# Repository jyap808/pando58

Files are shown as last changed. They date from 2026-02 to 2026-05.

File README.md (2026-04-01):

# Pando58

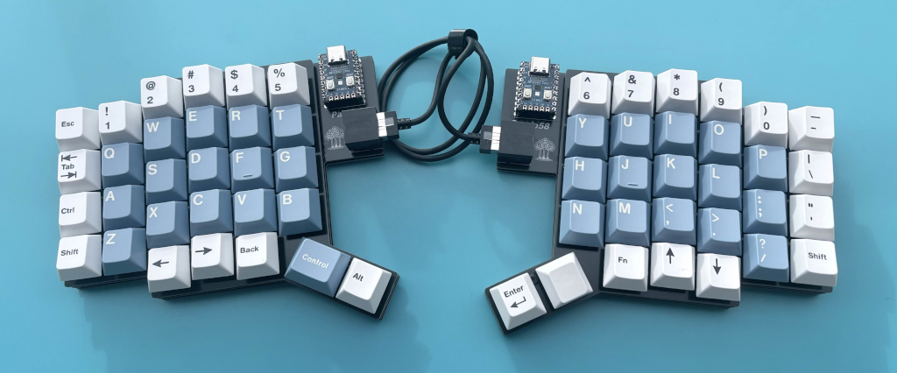
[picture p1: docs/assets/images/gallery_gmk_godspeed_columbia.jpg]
Pando58 with GMK Godspeed Colombia


Pando58 is a modern RP2040 Zero-based 58-key column staggered split keyboard. The PCB supports hotswap sockets OR soldered switches. The interconnect uses RJ45 ports as opposed to TRRS, which improves reliability and allows for hotplugging.

> [!NOTE]
> 📘 The **[Documentation pages](https://jyap808.github.io/pando58)** contain a Bill of Materials, Build guide, Firmware guide and Gallery.

> [!TIP]
> 🚀 Want to build one? Official PCB sets and full DIY kits are available on [Etsy](https://www.etsy.com/listing/4478359437/). Your support helps me keep this project open-source and encourages the development of new models!

## ⌨️ Overview

- **Layout:** Split ergonomic, 58 keys total  
- **Split connection:** RJ45 (no TRRS)  
- **MCU:** 2× RP2040 Zero  
- **Firmware:** Vial  

## 💡 Design Philosophy

Pando58 was designed to avoid unnecessary complexity and common failure points found in many split keyboards.

### Why RJ45 instead of TRRS?

TRRS cables are widely used in split keyboards, but they have a major drawback:

- ❌ **Not hot-plug safe** — plugging or unplugging can short pins and damage MCUs

Pando58 uses **RJ45** to solve this:

- ✅ Hot-plug safe
- ✅ Mechanically robust
- ✅ Readily available cables and plugs
- ✅ Clear pin separation and predictable wiring

For more details on the design and development process, see my [blog post](https://julianyap.com/posts/2026-03-26/).

## 🟢 Electronics

- **MCUs:** 2× RP2040 Zero  
- **PCBs:** Dedicated left and right designs (not reversible)

### Why dedicated PCBs?

Reversible PCBs often introduce increased chance of assembly errors.

Pando58 intentionally uses **separate left and right PCBs** to:
- Simplify assembly
- Reduce mistakes
- Improve electrical clarity

## ⚡ Switch & Diode Support

Pando58 is designed to accommodate different builder preferences and budgets:

- **MX switches**
- **Hot-swap sockets** (optional)
- **Solder-only sockets** (no hot-swap sockets required)
- **Diodes**
  - Supports **SMT diodes**
  - Supports **through-hole diodes**

Choose the configuration that best fits your workflow and tooling.

## 💾 Firmware

- **Vial firmware provided** (see `keyboards/` directory)
- Instant key remapping
- No recompiling required
- Works out of the box once flashed
- Compiled firmware available in [Releases](https://github.com/jyap808/pando58/releases)

## 📦 Case Options

Pando58 is intentionally flexible in enclosure options:

### FR4 Sandwich Case

- Minimal
- Affordable
- Easy to manufacture
- Gerber files are available in [Releases](https://github.com/jyap808/pando58/releases)

### 3D-Printable Case

- Allows experimentation with angle and height
- Source FreeCAD file in `case/` directory
- Ready-to-print STL available on [Printables](https://www.printables.com/model/1647072-pando58-case)

## 🛠️ Tooling & Design

- Generated using **Ergogen**
- Custom footprints created for:
  - RJ45 connector
  - RP2040 Zero (heavily modified from existing designs)

## 📷 Photos

Additional photos are available in the [Gallery](https://jyap808.github.io/pando58/gallery).

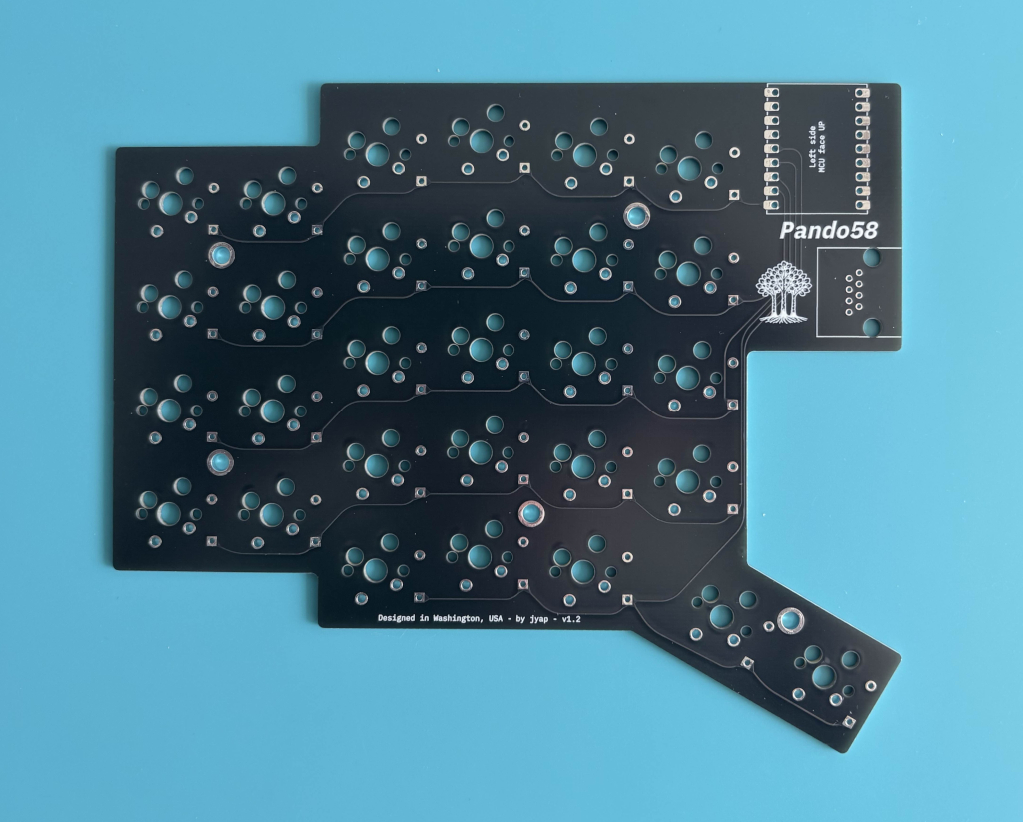
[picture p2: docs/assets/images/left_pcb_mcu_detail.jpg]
Left PCB top side

Left PCB top side

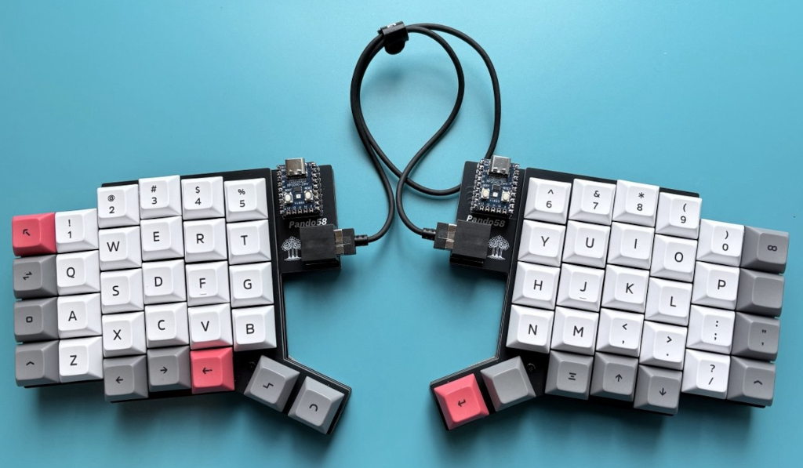
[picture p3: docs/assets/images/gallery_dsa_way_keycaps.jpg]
DSA Way Keycaps

Standard layout build with DSA Way keycaps

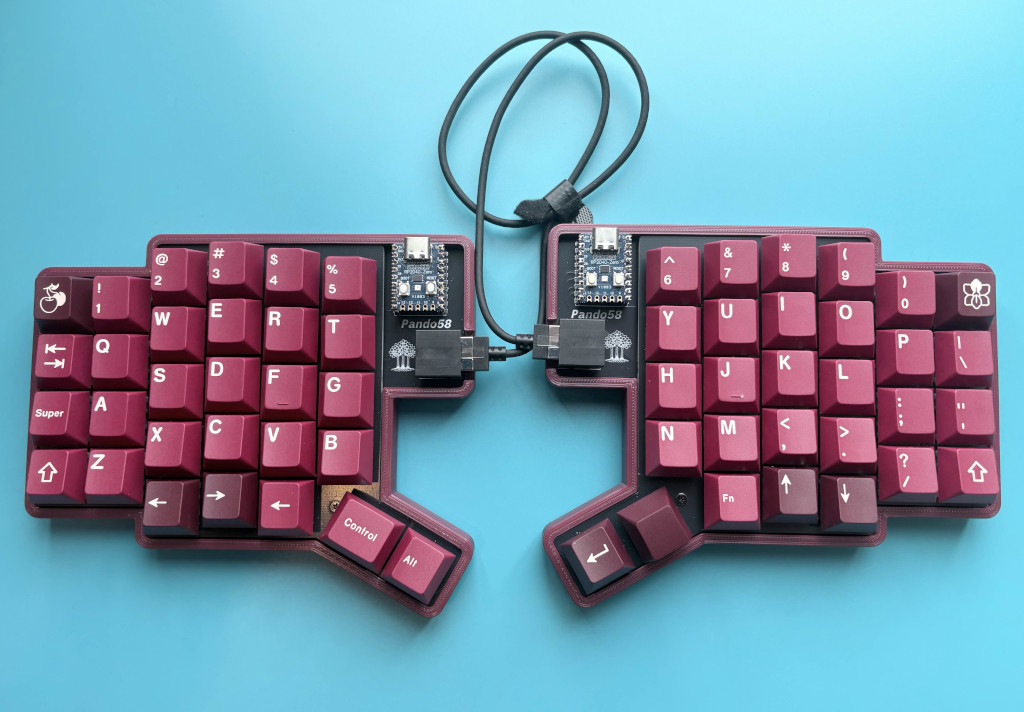
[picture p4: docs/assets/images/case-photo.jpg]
Pando58 3D printed case

3D printed case with Keykobo Cherries

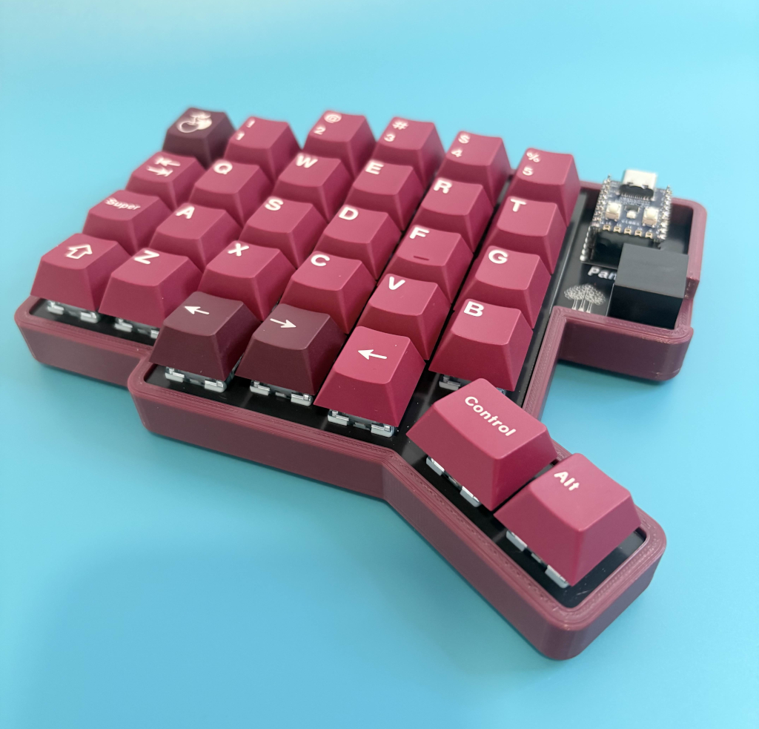
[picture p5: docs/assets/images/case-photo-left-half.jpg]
Pando58 3D printed case - left half

3D printed case - left half

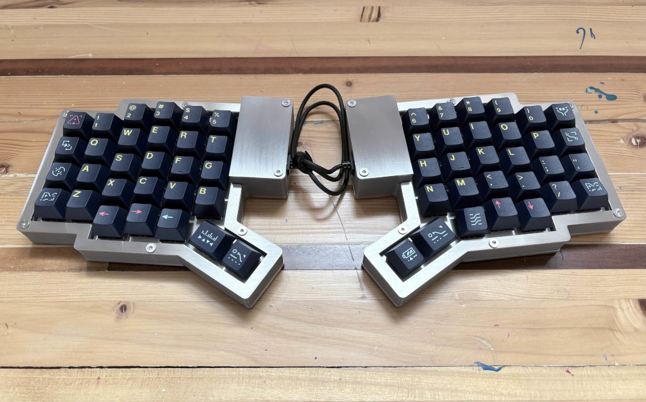
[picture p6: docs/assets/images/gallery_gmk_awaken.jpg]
GMK Awaken

Custom stainless steel and 3D printed case - GMK Awaken keycaps.

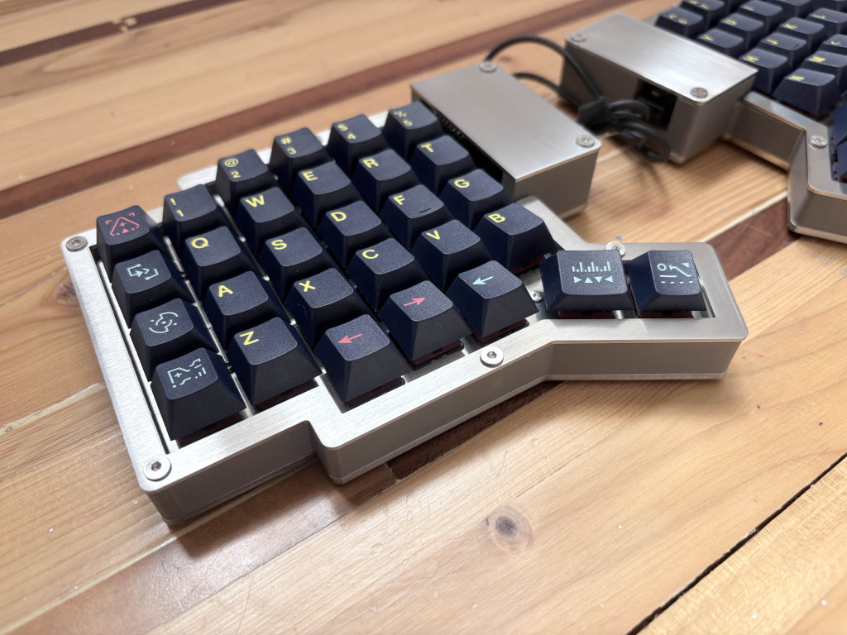
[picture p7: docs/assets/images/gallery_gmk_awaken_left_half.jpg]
GMK Awaken Left Half

The same build from a different angle showing the left half.

## 📄 License



[Pando58 Keyboard](https://github.com/jyap808/pando58) © 2026 by [Julian Yap](https://julianyap.com/) is licensed under [CC BY-SA 4.0](http://creativecommons.org/licenses/by-sa/4.0/?ref=chooser-v1)

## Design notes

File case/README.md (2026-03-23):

# Pando58 Case

Pando58 Case

3D printable case for Pando58 keyboard.

This replaces the default FR4 bottom piece. The assembled keyboard uses: switch plate + PCB + bottom case (this piece).

**Note:** This model represents the **LEFT side** only. To print the right side, mirror the model in your slicer.

## Printing

The ready-to-print STL file is available on [Printables](https://www.printables.com/model/1647072-pando58-case).

Pando58 Case - Left Half

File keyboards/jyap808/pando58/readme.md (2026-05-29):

# Pando58

Pando58 - 3D printed case

Pando58 - Layered build

*58-key columnar split keyboard driven by RP2040 Zero controllers, utilizing RJ45 sockets for interconnect.*

[Build guide](https://jyap808.github.io/pando58)

* Keyboard Maintainer: [jyap808](https://github.com/jyap808)
* Hardware Availability: [github/jyap808/pando58](https://github.com/jyap808/pando58)
* Hardware Supported: RP2040 Zero

Make example for this keyboard (after setting up your build environment):

    make jyap808/pando58:default

Flashing example for this keyboard:

    make jyap808/pando58:default:flash

See the [build environment setup](getting_started_build_tools) and the [make instructions](getting_started_make_guide) for more information. Brand new to QMK? Start with our [Complete Newbs Guide](newbs).

## Bootloader

Enter the bootloader in 3 ways:

* **Bootmagic reset**: Hold down the key at (0,0) in the matrix (usually the top left key or Escape) and plug in the keyboard
* **Physical reset button**: Briefly press the button on the back of the PCB - some may have pads you must short instead
* **Keycode in layout**: Press the key mapped to `QK_BOOT` if it is available

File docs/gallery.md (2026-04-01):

# Gallery

Pando58 supports a variety of case and keycap options. Here are some examples to inspire your build.

## Case Options

### Standard Layered Build

DSA Way Keycaps

DSA Way keycaps in red accents by FK Keycaps. DSA is a uniform keycap height.

GMK Godspeed Columbia

GMK Godspeed Colombia keycaps with Cherry Icebergo PBT modifier kit keycaps (from keeb.io).

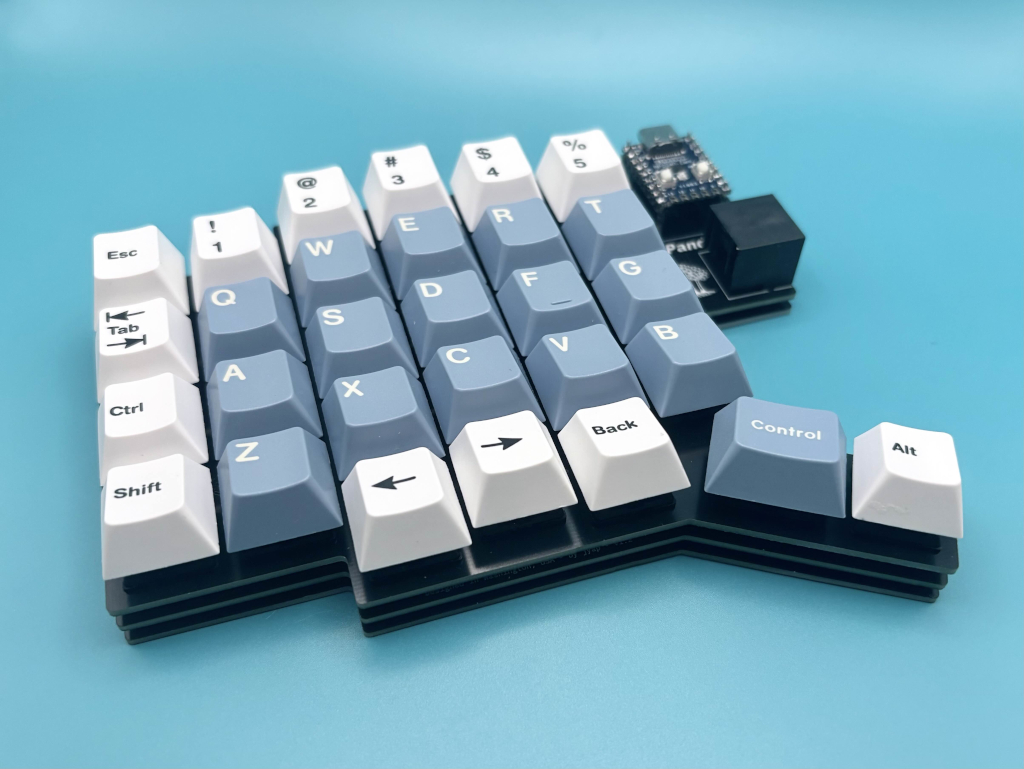
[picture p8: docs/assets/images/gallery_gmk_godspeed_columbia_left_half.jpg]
GMK Godspeed Columbia Left Half


The same build from a different angle showing the left half.

### 3D Printed Case

[3D printable case](https://www.printables.com/model/1647072-pando58-case) for Pando58 keyboard.

This replaces the default FR4 bottom piece. The assembled keyboard uses: switch plate + PCB + bottom case (this piece).

Pando58 3D printed case

Keykobo Cherries with 40s set keycaps, printed with Ambrosia ASA filament in cardovan.

Pando58 3D printed case - left half

The same build from a different angle showing the left half.

### Custom Case Build

This is my custom case build made from stainless steel sheet metal mixed with 3D printed case.

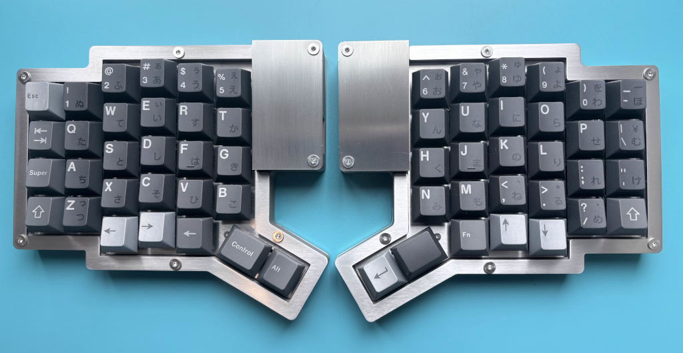
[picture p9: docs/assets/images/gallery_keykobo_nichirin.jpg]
Keykobo Nichirin


Keykobo Nichirin with 40s set keycaps.

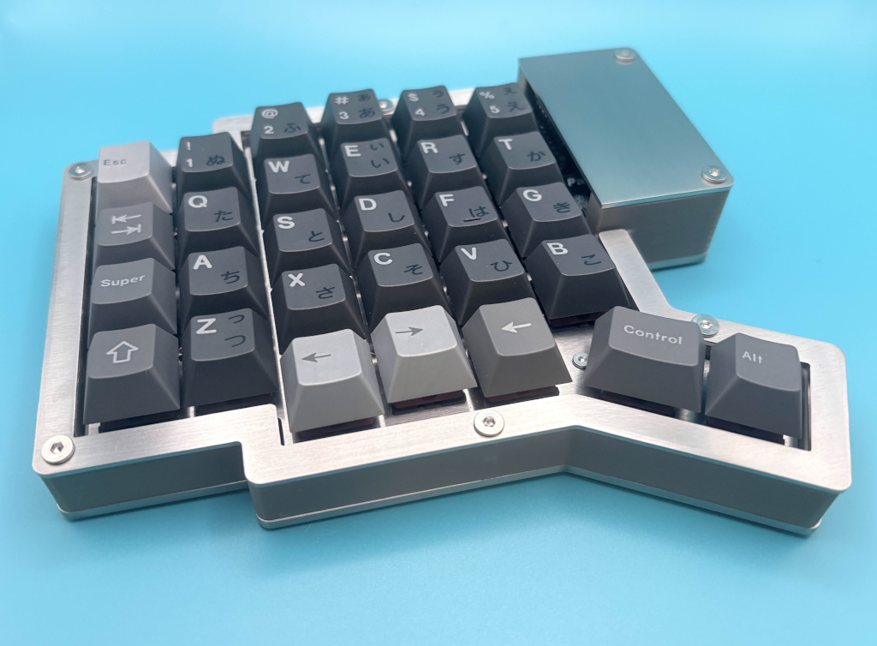
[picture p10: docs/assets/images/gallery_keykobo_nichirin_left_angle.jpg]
Keykobo Nichirin Left Angle


The same build from a different angle showing the left half.

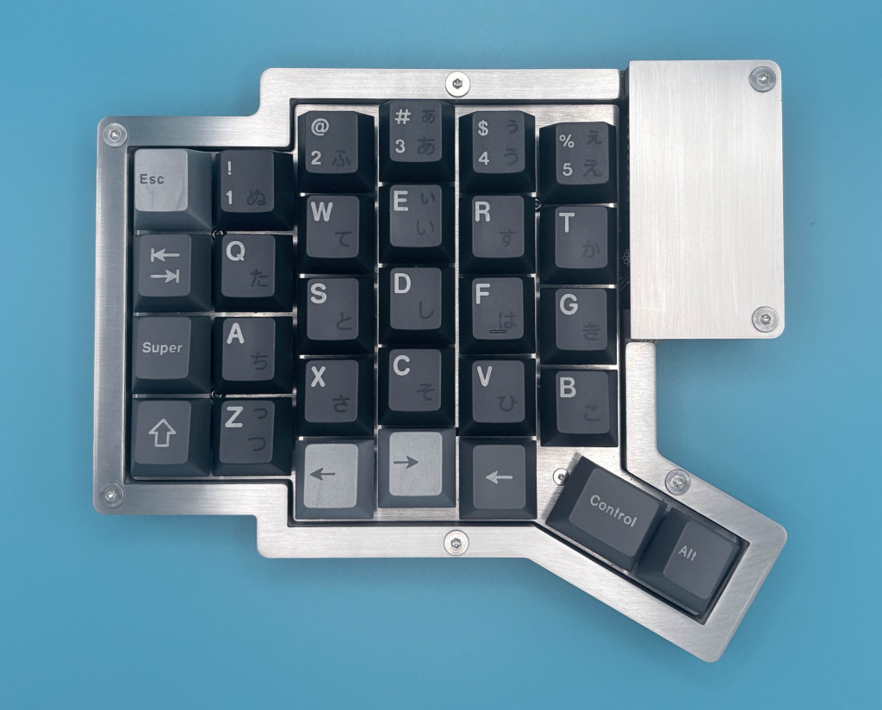
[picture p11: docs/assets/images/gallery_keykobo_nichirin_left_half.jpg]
Keykobo Nichirin Left Half


The same build from a top view showing the left half.

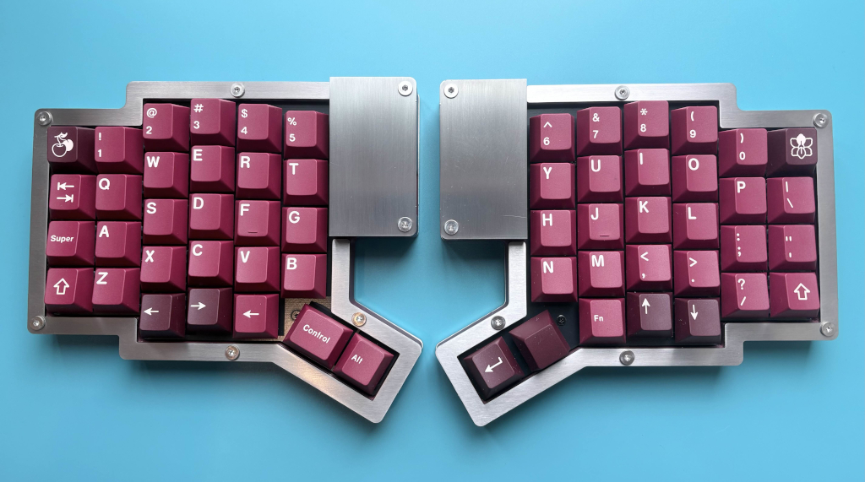
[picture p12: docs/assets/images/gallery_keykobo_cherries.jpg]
Keykobo Cherries


Keykobo Cherries with 40s set keycaps.

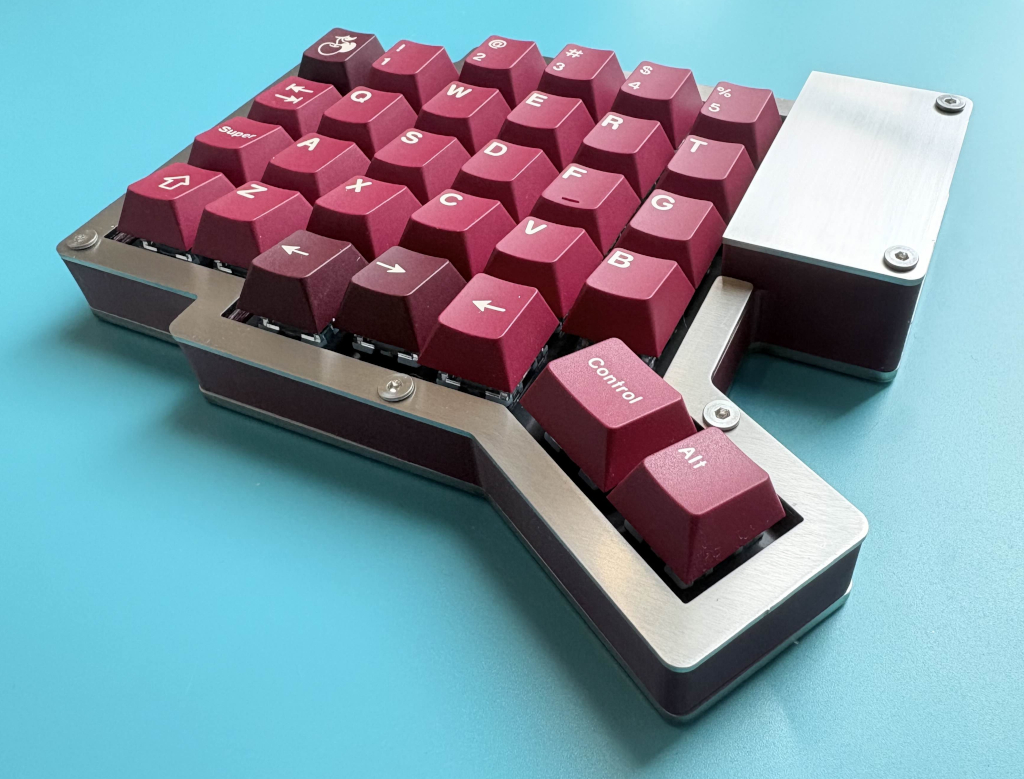
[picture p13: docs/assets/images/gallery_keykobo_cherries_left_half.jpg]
Keykobo Cherries Left Half


The same build from a different angle showing the left half.

GMK Awaken

GMK Awaken keycaps.

GMK Awaken Left Half

The same build from a different angle showing the left half.

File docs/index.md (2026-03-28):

# Pando58 Keyboard

Pando58

Pando58 is a modern RP2040 Zero-based 58-key column staggered split keyboard. The PCB supports hotswap sockets OR soldered switches. The interconnect uses RJ45 ports as opposed to TRRS, which improves reliability and allows for hotplugging.

🚀 Want to build one? Official PCB sets and full DIY kits are available on [Etsy](https://www.etsy.com/listing/4478359437/). Your support helps me keep this project open-source and encourages the development of new models!

## Design Philosophy

Pando58 was designed to avoid unnecessary complexity and common failure points found in many split keyboards. It features:

- Wired connection only (no wireless)
- No LEDs, encoders, or OLED displays
- Simple, reliable construction
- Focus on core typing experience

For more details on the design and development process, see my [blog post](https://julianyap.com/posts/2026-03-26/).

## Inspiration

Pando58 came about through wanting a flat PCB version of my [hand-wired Cosmos Dactyl](https://julianyap.com/posts/2025-11-16-1763340628/). The key layout was inspired by the [Kinesis Advantage2](https://kinesis-ergo.com/keyboards/advantage2-keyboard/#layout) with a simplified thumb cluster.

While not being directly inspired by other keyboards, it can be seen as similar to other keyboards like the Silakka54, Lily58, Sofle and ErgoDox.

### Name

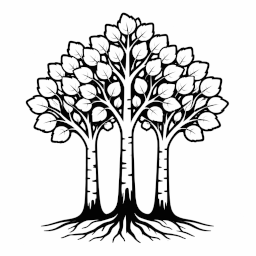
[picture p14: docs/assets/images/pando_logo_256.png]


Pando58 is named after the [Pando tree](https://youtu.be/SwBgSbPvg7Q). I had found out from a [really cool presentation](https://neal.fun/size-of-life/) that Pando was the Earth's largest organism by mass.

This idea maps nicely onto split keyboards. At first glance, a split keyboard looks like two separate devices. But electrically and functionally, they operate as one system: two halves connected together to behave as a single keyboard.

The name Pando58 reflects that concept. Like the Pando colony, the keyboard is composed of multiple visible parts that are actually one coherent organism working together. The two halves mirror each other, share firmware architecture, and communicate continuously.

## Getting Started

Visit the [Build](build.md) page to learn about the build process.

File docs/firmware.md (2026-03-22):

# Firmware

Pando58 uses Vial firmware which needs to be installed on the RP2040 Zero MCUs. Once installed, [Vial](https://get.vial.today/) (the application) is used to configure the keyboard.

## Getting Vial

Download Vial (the desktop application) from the [official website](https://get.vial.today/) for your platform.

Alternatively, you can use [Vial Web](https://vial.rocks) in your browser — no download required.

## Installing Firmware

There are two ways to get the latest Vial firmware for Pando58:

> **Note:** Pando58 is a split keyboard with an MCU on each half. Both MCUs will need to be flashed with the Vial firmware.

1. **Easy method** — Download precompiled firmware from [GitHub Releases](https://github.com/jyap808/pando58/releases) and flash via drag-and-drop (recommended for most users).
2. **Manual build method** — Clone the vial-qmk repo, build locally, and flash via CLI.

### Easy Method: Download from Releases + Drag-and-Drop

1. Go to the [Releases page](https://github.com/jyap808/pando58/releases)

2. Download the latest `.uf2` file (e.g., `jyap808_pando58_vial.uf2`)

3. Put the keyboard into bootloader mode by holding the BOOT button on the MCU while plugging in the USBC cable. The keyboard should mount as a removable drive (e.g., "RPI-RP2", "PICO", or similar).

4. Drag the downloaded `.uf2` file onto the mounted drive

5. The drive will auto-eject and the keyboard will reboot with the new firmware

### Manual Build Method: CLI Build + Flash (Advanced)

1. Clone the official Vial QMK fork:

        git clone https://github.com/vial-kb/vial-qmk.git
        cd vial-qmk

2. Initialize submodules (important for QMK dependencies):

        make git-submodule

3. Clone or download the Pando58 keyboard folder from the [GitHub repo](https://github.com/jyap808/pando58).

    Copy the entire `keyboards/jyap808/pando58/` folder into `vial-qmk/keyboards/jyap808/pando58/`.

4. Compile the Vial firmware:

        make jyap808/pando58:vial

    This produces `jyap808_pando58_vial.uf2`.

5. Flash using the CLI:

        qmk flash jyap808_pando58_vial.uf2

    Make sure you're in the directory with the `.uf2` file, or use the full path.

## Configuring with Vial

Open [Vial](https://get.vial.today/) to configure the keyboard. The Pando58 should connect automatically when the firmware is installed.

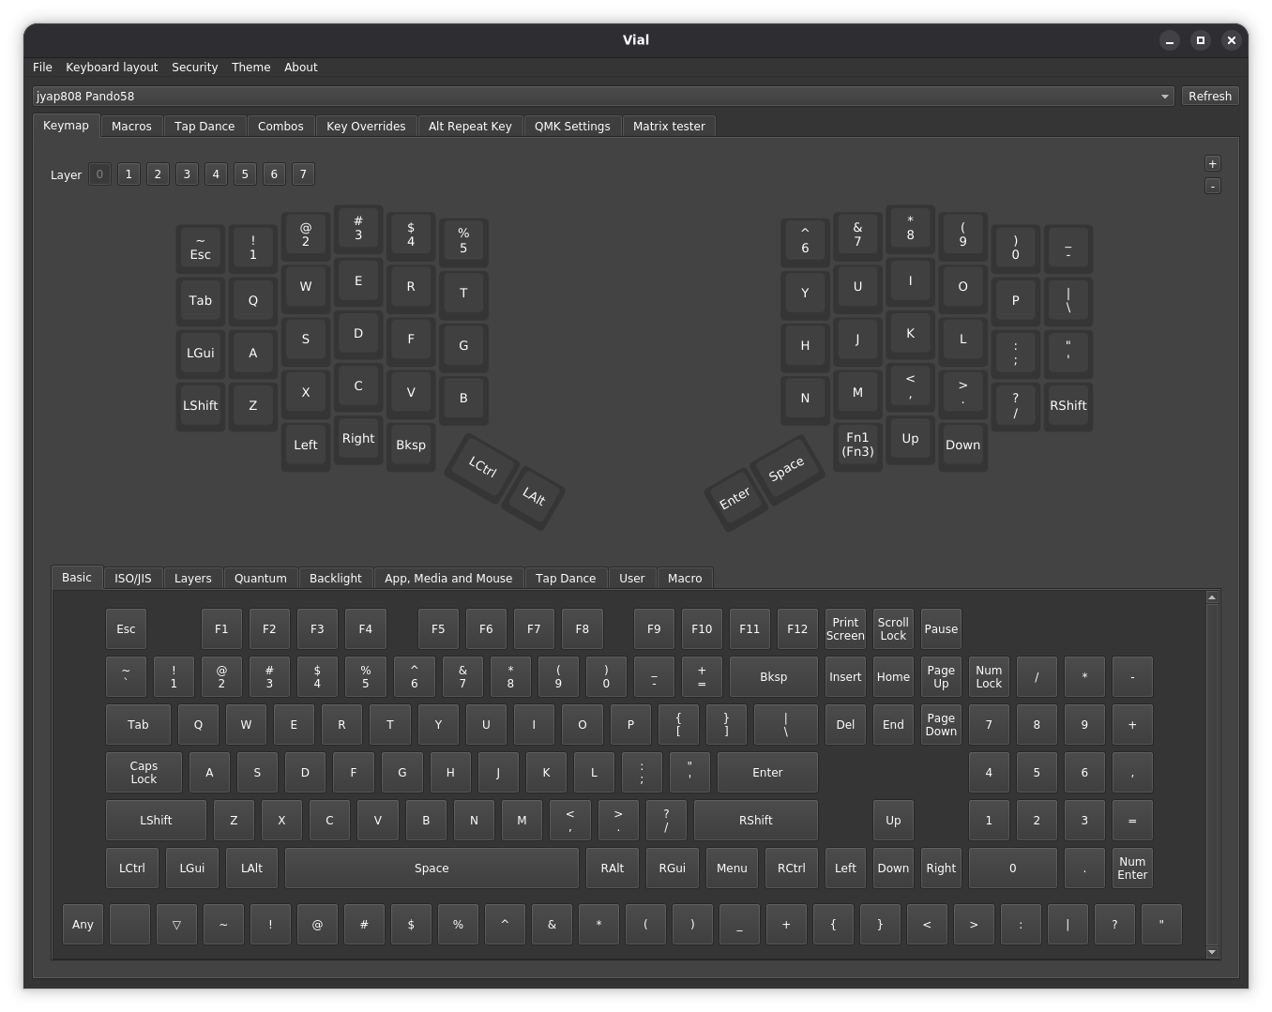
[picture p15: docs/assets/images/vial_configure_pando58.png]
Vial application showing Pando58 keyboard configuration


Vial allows you to remap keys, create layers, and configure macros for your Pando58 keyboard.

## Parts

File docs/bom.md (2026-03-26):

# Bill of Materials

This BOM is for the basic FR4 PCB setup with 2x PCBs (one for each half), 2x switch plates, and 2x bottom plates. Other setups like 3D printed cases are possible but not covered here.

## Components

### Required

#### Electronics

- 2x RP2040 Zero (Waveshare or [clones](https://www.amazon.com/dp/B0DXL1KDY7?tag=fdb-20), one for each half)
- 58x Diodes (1N4148W SMT or [1N4148 through-hole](https://www.amazon.com/dp/B079KJ91JZ?tag=fdb-20))
- 2x RJ45 ports ([Molex 438600001](https://www.digikey.com/en/products/detail/molex/0438600001/410212) or clones with same footprint)
- 2x Pando58 PCBs (left and right, not reversible)
- 4x 9-pin male header pins ([for RP2040 Zero MCU](https://www.amazon.com/dp/B07BRYLMK8?tag=fdb-20), 2 rows per half)

#### Switches & Keycaps

- 58x MX switches
- 58x keycaps

#### Hardware

- 10x M2 8mm brass standoffs ([5 per half](https://www.amazon.com/dp/B0FLGTHV32?tag=fdb-20))
- 20x M2 4mm screws ([10 per half](https://www.amazon.com/dp/B082XXVGT3?tag=fdb-20))
- 2x Pando58 switch plates
- 2x Pando58 bottom plates

#### Cables

- 1x USB-C cable (to connect to computer)
- 1x RJ45 cable ([for interconnect](https://www.amazon.com/dp/B0CMYYN58G?tag=fdb-20))

### Optional

#### Electronics

- 4x 9-pin female header sockets ([for removable MCU installation](https://www.amazon.com/dp/B07BRYLMK8?tag=fdb-20), 2 rows per half)

#### Switches & Keycaps

- 58x [MX hotswap sockets](https://www.amazon.com/dp/B0B4W9YMGM?tag=fdb-20)

#### Hardware

- 8x 3M SJ5302 bumpons ([4 per half](https://www.digikey.com/en/products/detail/3m/SJ5302/2345107))

### Assembly Tools

- Soldering iron and solder
- Screwdrivers
- Kapton tape (optional)
- Flush cutters (optional)
- Tweezers (optional)
- Multimeter (optional)

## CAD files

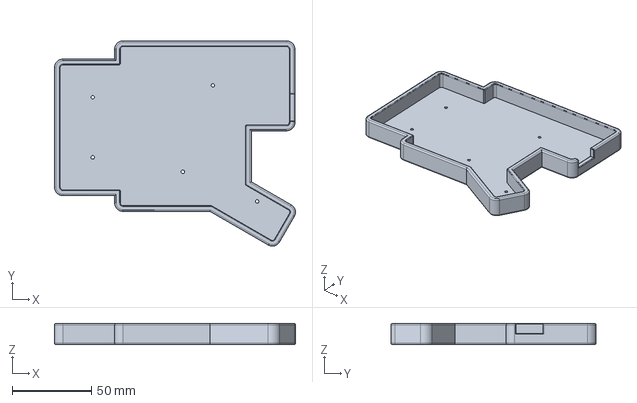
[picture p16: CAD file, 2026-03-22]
case/Pando58Case.FCStd
152.3 x 129.7 x 13.5 mm

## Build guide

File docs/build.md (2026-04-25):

# Build Guide

## Overview

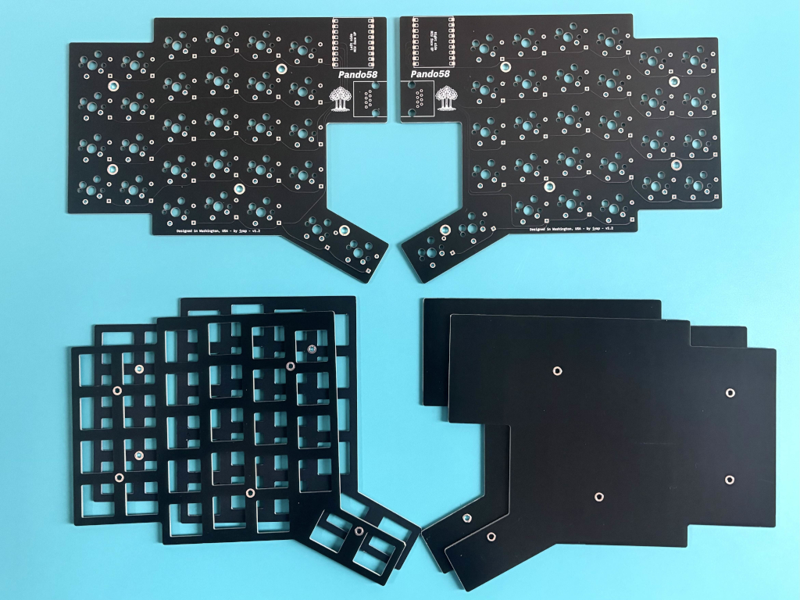
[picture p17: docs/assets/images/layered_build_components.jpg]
All PCB Components for Layered Build


This guide covers the **layered build type** using the dedicated PCBs, 2 reversible switch plates, and 2 reversible bottom plates.

> **Note:** [3D printed case builds](gallery.md#3d-printed-case) are similar (the one-piece case replaces the bottom plates) but are not covered here. Sandwich builds are also not covered.

> **Reference:** See the [Bill of Materials](bom.md) for a complete list of components and quantities needed.

Left PCB MCU Detail

This guide walks through building **one half** (the left half) of the PCBs since the assembly is identical on both halves. Pictured above is the Left PCB top side.

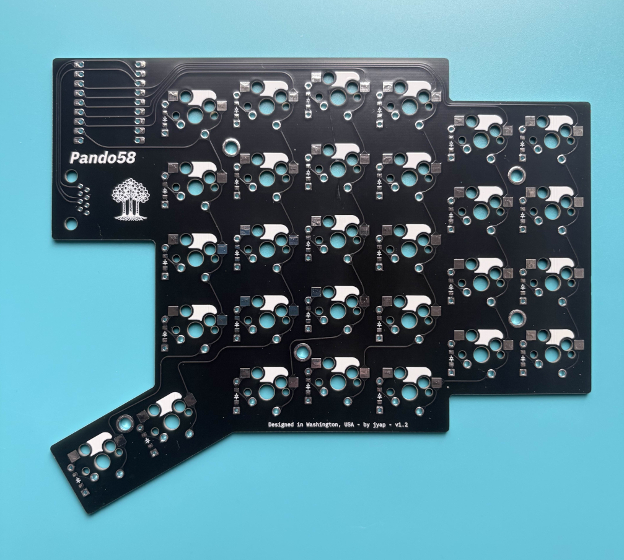
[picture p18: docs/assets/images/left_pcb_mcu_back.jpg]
Left PCB back side


Left PCB back side, ready to be assembled.

## Assembly Steps

This guide covers the following components in detail. Follow each section in order for best results:

1. [Diodes](#diodes) - Through-hole diode installation
2. [Hotswap Sockets](#hotswap-sockets) - MX-compatible switch sockets
3. [RJ45 Port - Interconnect](#rj45-port-interconnect) - Interconnect ports
4. [RP2040 Zero MCU](#rp2040-zero-mcu) - Microcontroller installation
5. [Switches](#switches) - Switch and plate installation
6. [Keycaps and Optional Bumpons](#keycaps-and-optional-bumpons) - Final assembly

### Diodes

Pando58 supports **SMT (surface mount)**, **THT (through-hole)**, or a **combination of both** diodes. This guide covers through-hole diode installation.

> **Note:** If you're using SMT diodes, you should already be comfortable with surface mount soldering or follow a dedicated SMT guide.

**Required:** 58x 1N4148 diodes (29 per half)

#### Bending Diodes

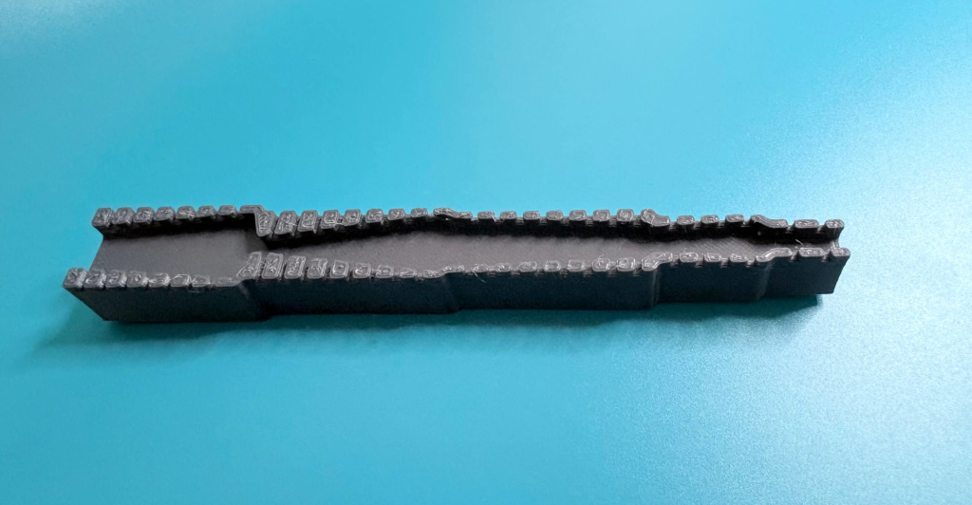
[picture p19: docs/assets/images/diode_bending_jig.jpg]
Diode Bending Jig


Use a bending jig for consistent, clean bends. You can download the 3D model from [Printables](https://www.printables.com/model/739930-bending-jig).

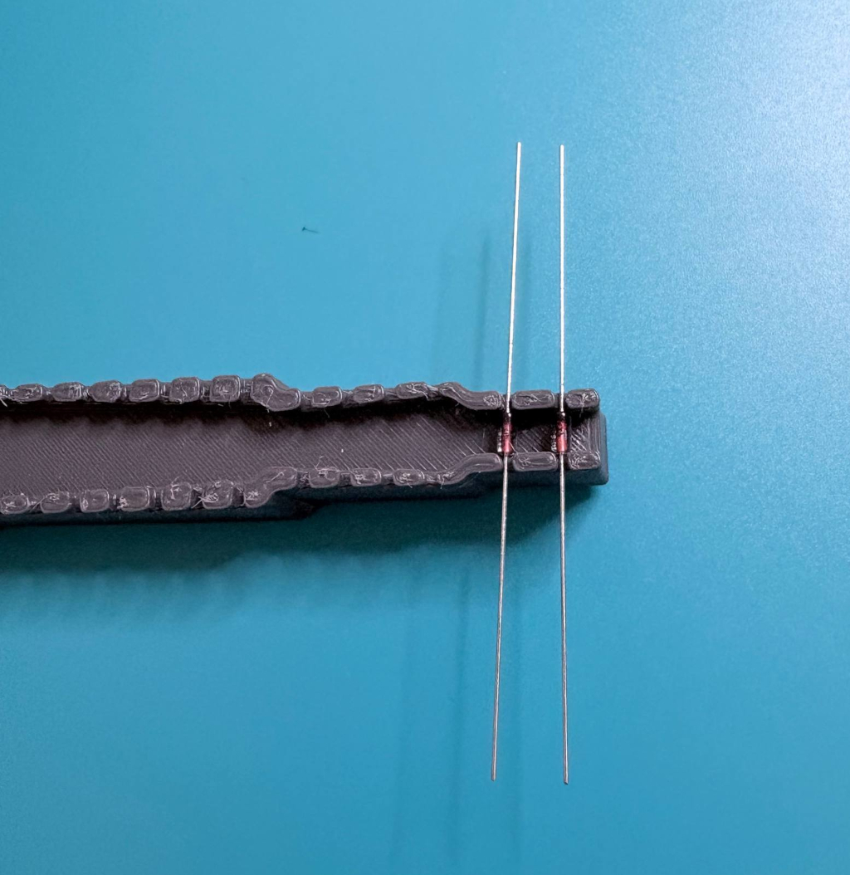
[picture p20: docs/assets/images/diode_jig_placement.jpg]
Diode Placement in Jig


Place the diodes in the jig as shown above.

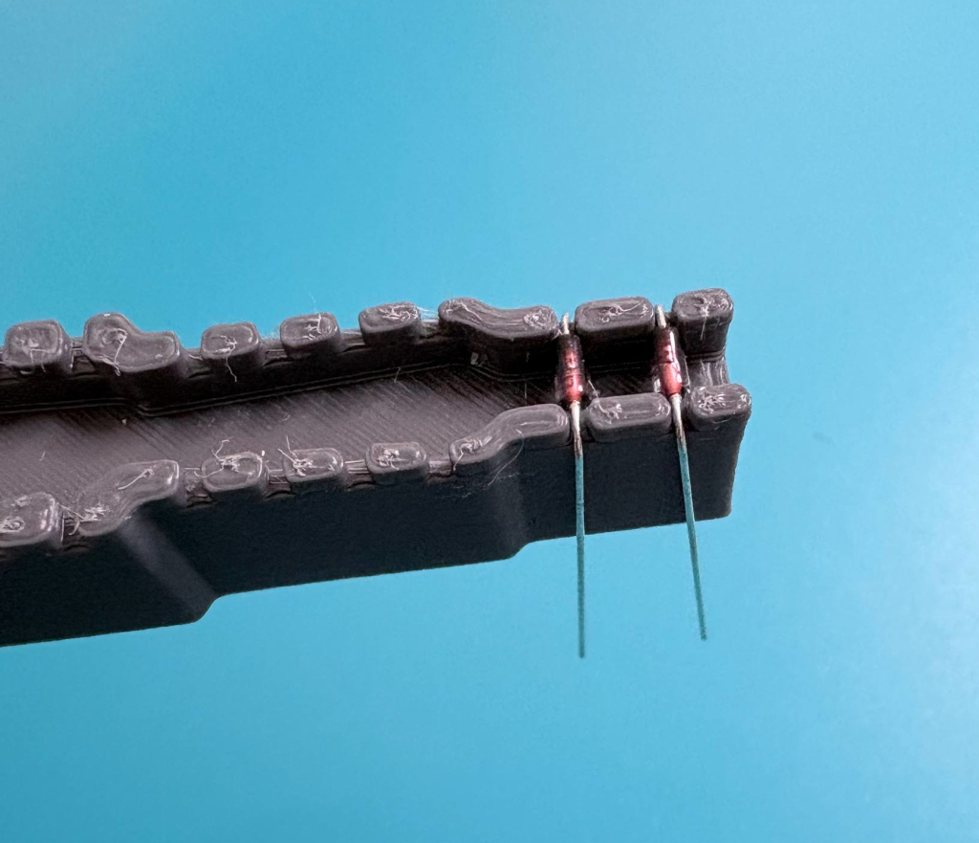
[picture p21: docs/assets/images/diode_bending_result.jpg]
Bent Diodes


The jig bends diodes to a **7.5mm standoff distance**. You can hand-bend diodes at 7.5mm, but the jig produces cleaner, more consistent results.

#### Diode Orientation

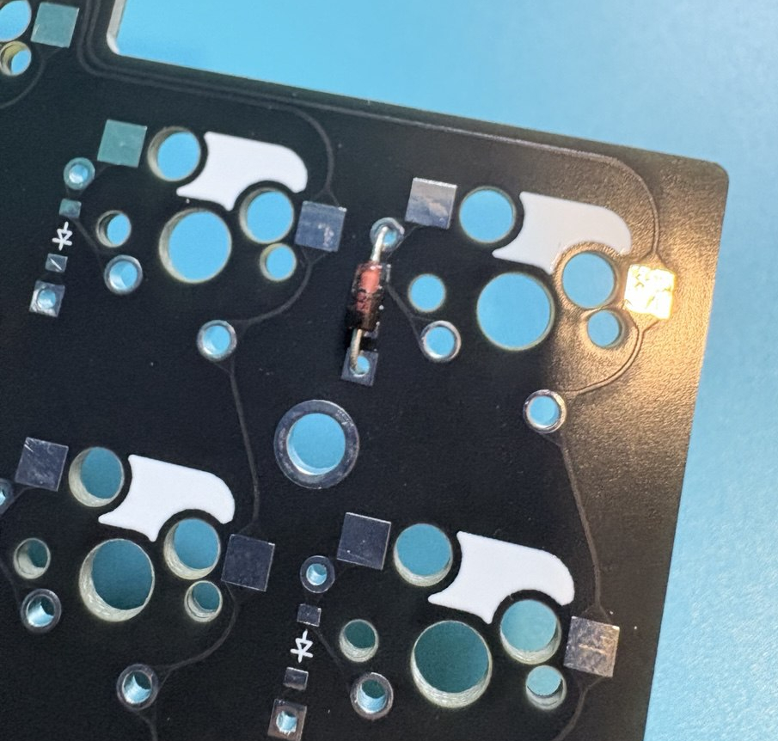
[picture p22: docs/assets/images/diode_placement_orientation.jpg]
Diode Placement Orientation


**Critical:** Diodes are polarity-sensitive components. The **black stripe** on the diode indicates the **cathode (-)** side and must align with the direction arrow shown on the PCB silkscreen.

- The diodes feed through the **BOTTOM** of the PCB
- The black stripe must face the direction of the arrow in the PCB diagram
- Getting this wrong will cause the keyboard to malfunction

#### Populating the Board

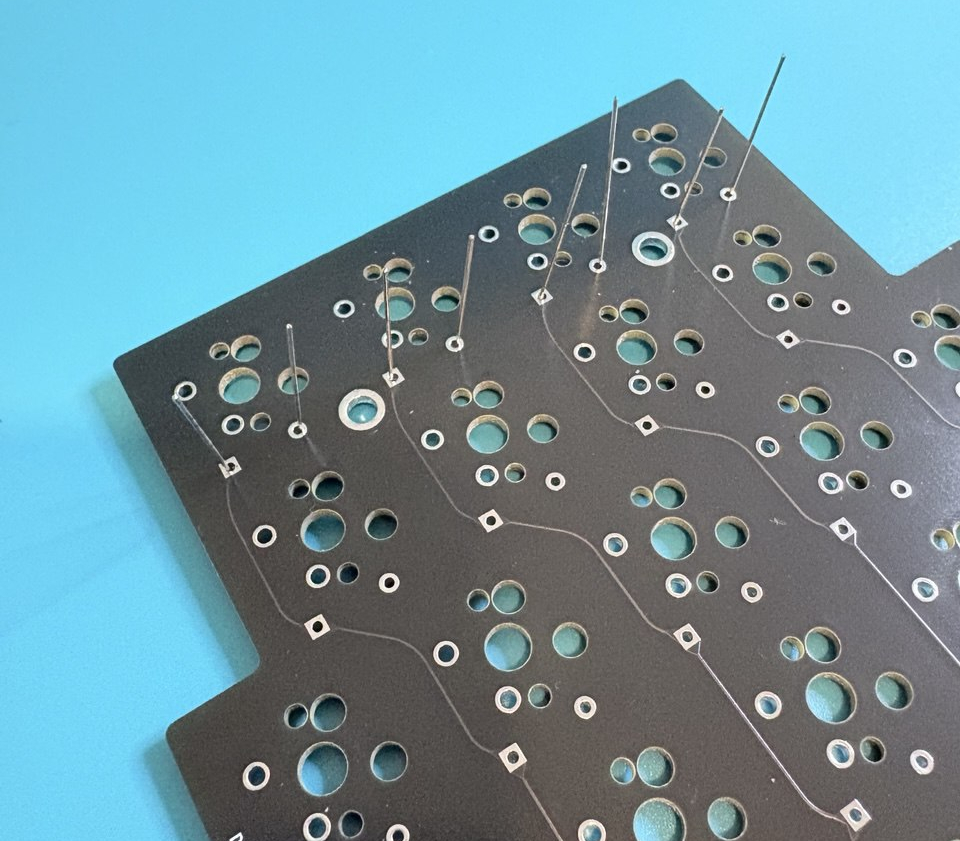
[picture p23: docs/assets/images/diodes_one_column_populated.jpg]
Diodes One Column Populated


Insert the diodes into one PCB half. The board above shows one column populated as an example.

> **Tip:** Solder one column at a time to keep the workspace organized and reduce the chance of diodes falling out before soldering.

#### Soldering Diodes

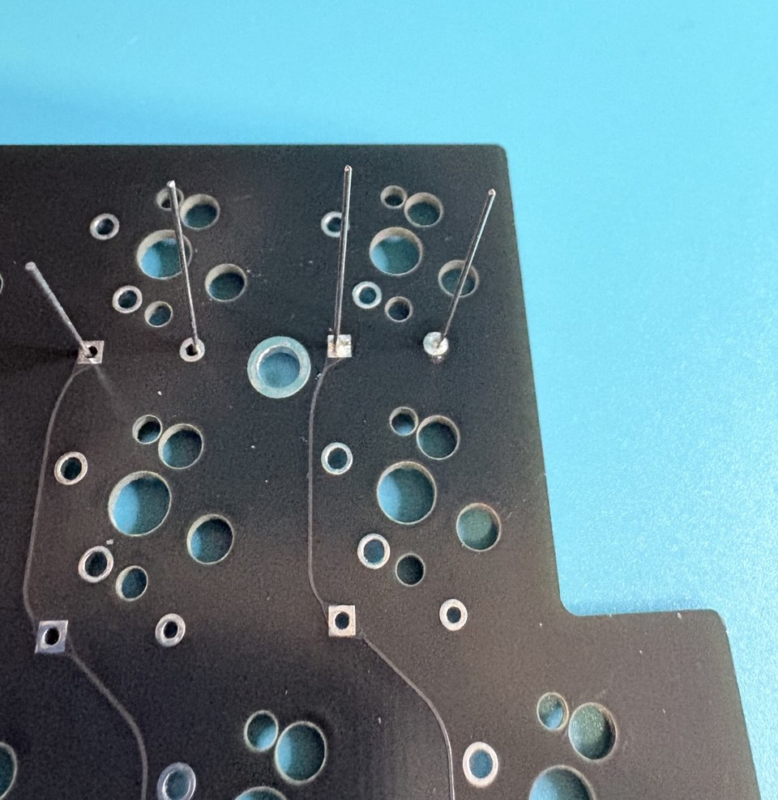
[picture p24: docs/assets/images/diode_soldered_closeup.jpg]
Diode Soldered Close-up


Solder the diodes through the **TOP side** of the PCB. Ensure the diodes lie **flat against the board** while soldering to prevent uneven joints.

**Key points:**

- Apply heat to the pad and leg simultaneously
- Feed solder to create a smooth, concave joint
- Avoid overheating (keep soldering time under 3 seconds per joint)
- Make sure diodes remain flat against the board

#### Trimming Excess Leads

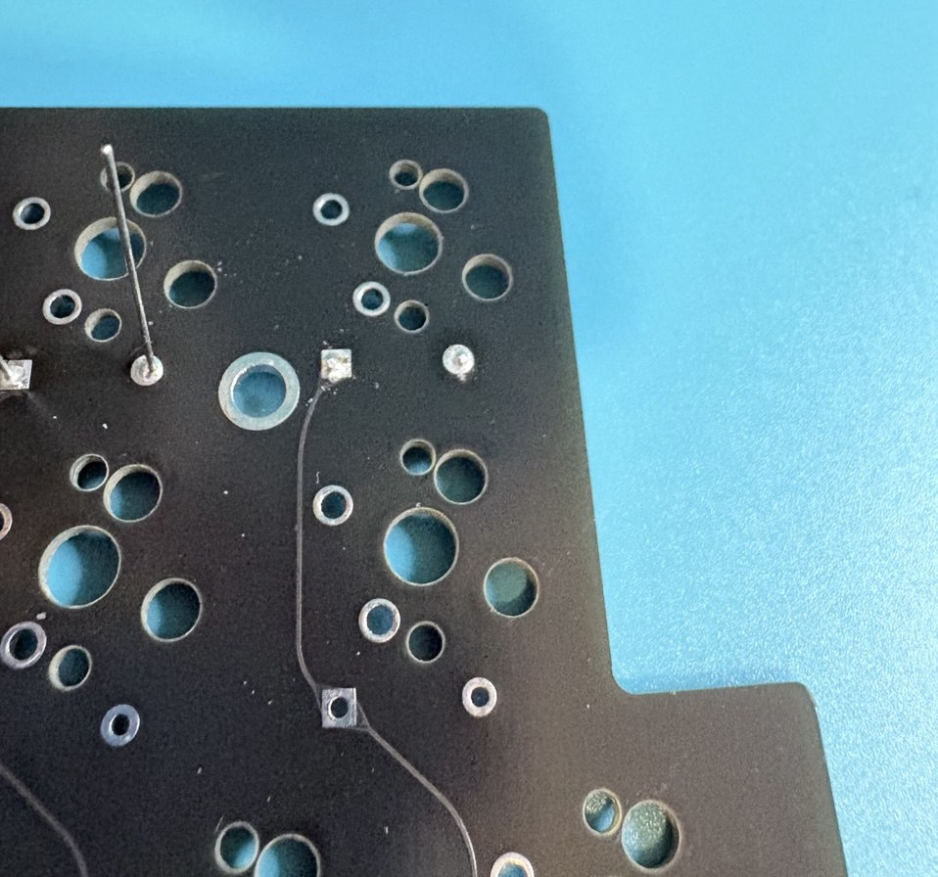
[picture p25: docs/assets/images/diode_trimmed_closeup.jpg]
Diode Trimmed Close-up


Use **flush cutters** to trim the diode legs close to the solder joint after soldering. This prevents sharp edges and reduces the risk of short circuits.

#### Completed Diode Installation

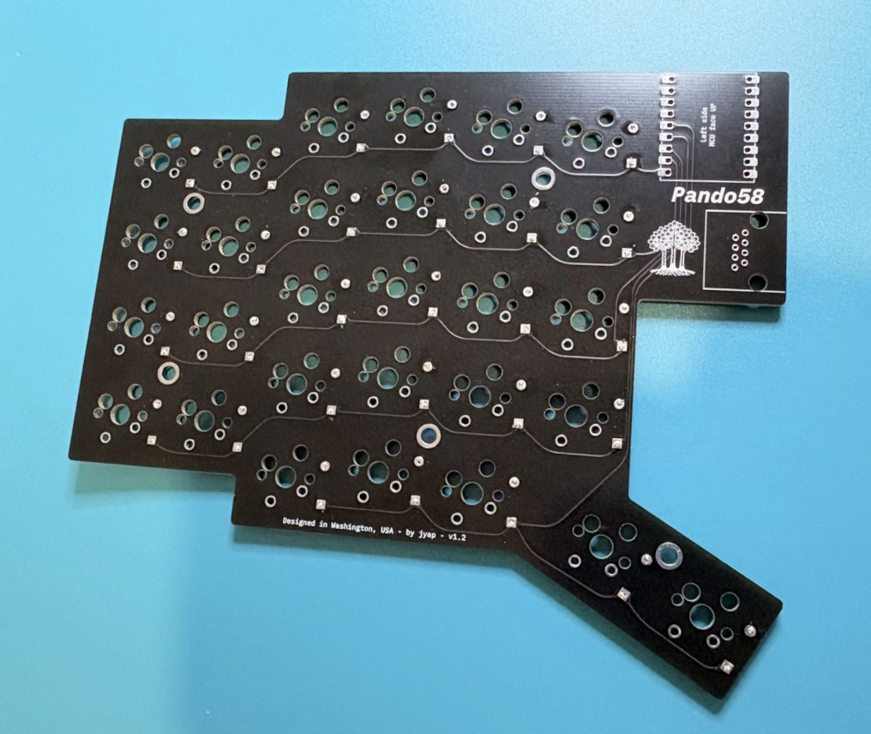
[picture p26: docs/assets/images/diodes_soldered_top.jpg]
Diodes Soldered Top Side


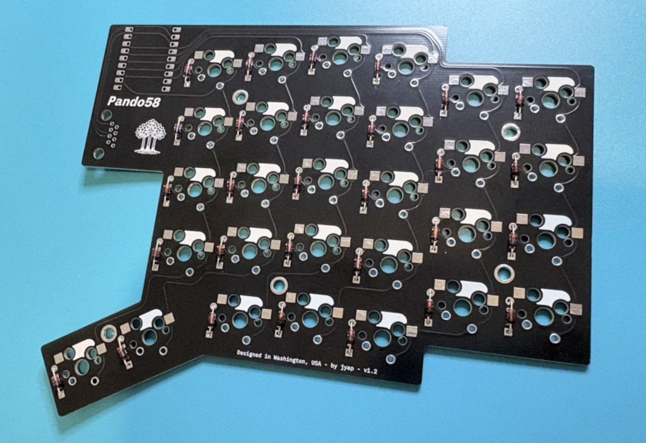
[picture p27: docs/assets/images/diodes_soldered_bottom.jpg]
Diodes Soldered Bottom Side


The top image shows all diodes soldered and trimmed from the top side. The bottom image shows the bottom side with all diodes in place with correct orientation.

**Verify before moving on:**

- All 29 diodes are soldered
- Black stripes align with PCB arrows (check from bottom side)
- No cold joints or excess solder
- All legs are trimmed flush

### Hotswap Sockets

Pando58 supports **hotswap sockets** or **soldered switches**.

- **Hotswap sockets** allow you to insert and remove switches without soldering
- **Soldered switches** are installed directly to the PCB (no sockets needed)

This section covers hotswap socket installation. If you're soldering switches directly, skip to the Soldered Switches section below.

> **Note:** Only **MX-compatible** hotswap sockets are supported. This PCB does not support Kailh hotswap sockets.

**Required:** 58x MX-compatible hotswap sockets (29 per half)

#### Placing Hotswap Sockets

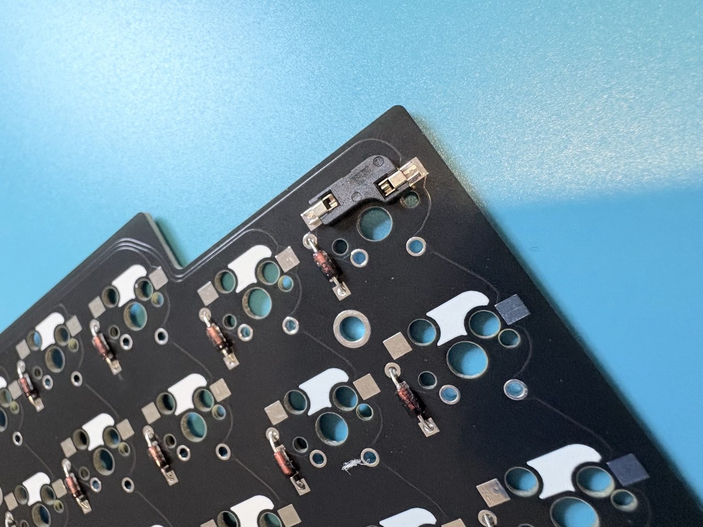
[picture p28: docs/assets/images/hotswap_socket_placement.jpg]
Hotswap Socket Placement


Place the hotswap sockets on the footprints on the **back side** of the PCB. The orientation is outlined in the footprint silkscreen - align each socket accordingly.

#### Soldering Hotswap Sockets

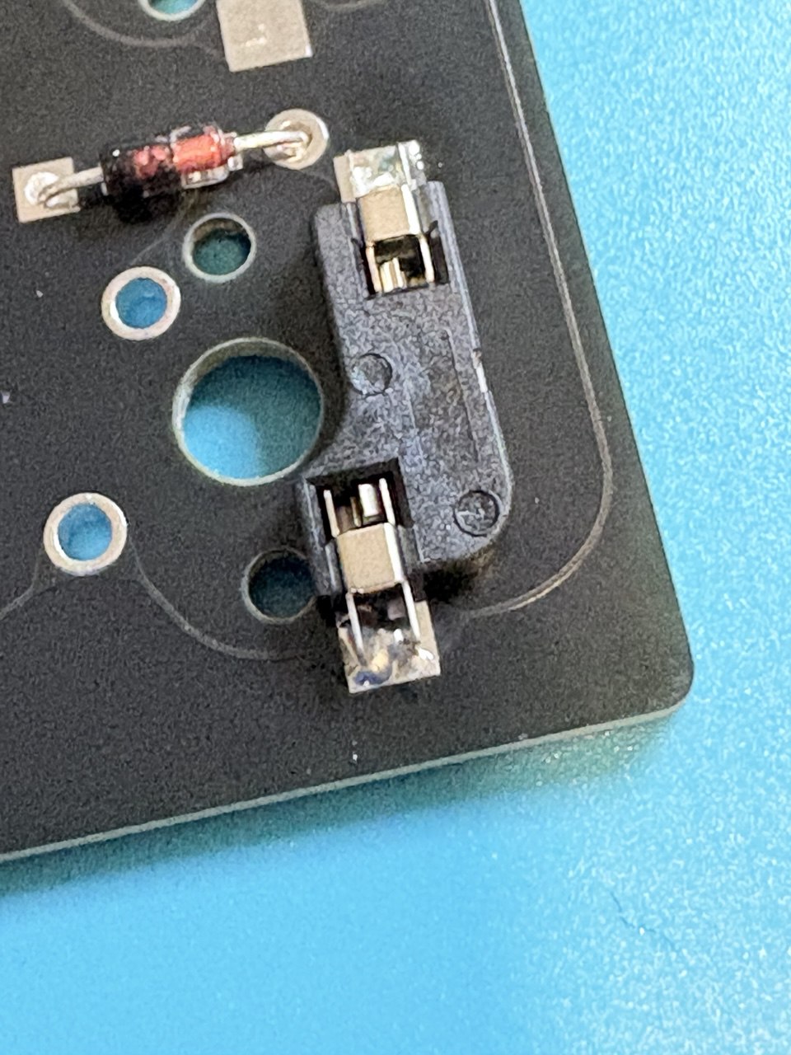
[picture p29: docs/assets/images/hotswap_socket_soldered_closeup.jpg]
Hotswap Socket Soldered Close-up


Heat each pad and apply solder to secure the socket. Solder **both sides** of each hotswap socket to ensure a solid connection.

**Key points:**

- Heat the pad before applying solder
- Ensure both sides of the socket are soldered
- Avoid bridging adjacent pads
- Don't overheat (sockets can be sensitive to excessive heat)

#### Completed Hotswap Installation

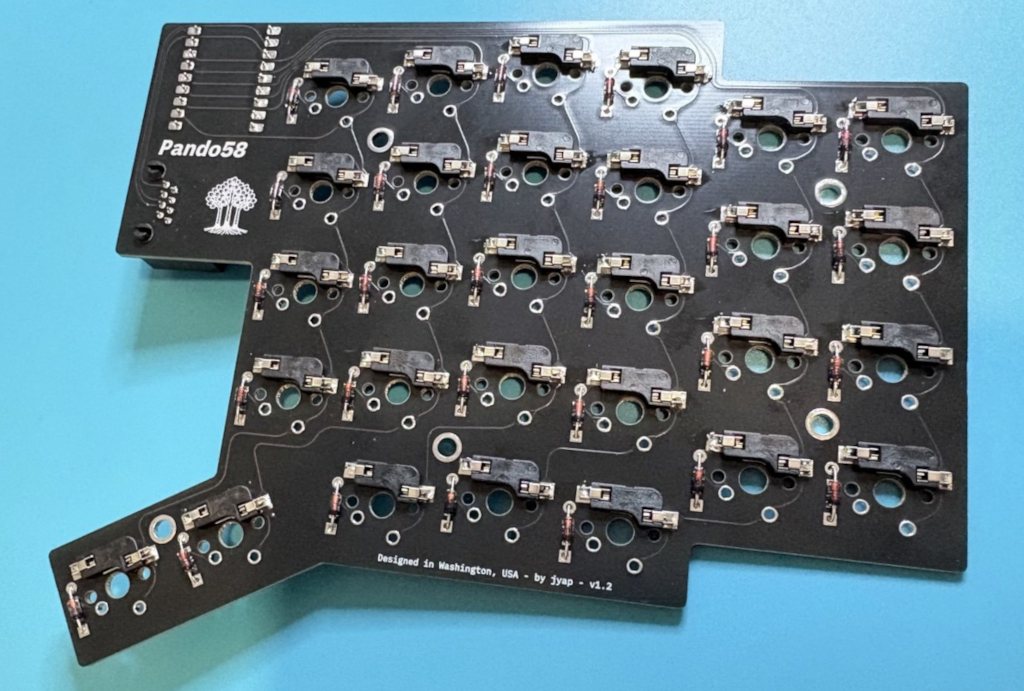
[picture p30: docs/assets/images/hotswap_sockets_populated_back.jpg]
Hotswap Sockets Populated Back Side


The image above shows a fully populated back side with all 29 hotswap sockets soldered.

**Verify before moving on:**

- All 29 hotswap sockets are soldered
- Both sides of each socket have good solder joints
- No solder bridges between adjacent pads
- Sockets are flush with the PCB

### Soldered Switches (Alternative)

> **Important:** Attach the switches to the switch plate BEFORE soldering them to the PCB.

If you're not using hotswap sockets, you can solder switches directly to the PCB:

1. First, attach switches to the switch plate (see Switch Plate section)
2. Insert the switch + plate assembly from the **top side** of the PCB
3. Ensure the 2 pins align with the correct pads
4. Solder the pins from the bottom side
5. Repeat for all 29 switches

> **Note:** Switches soldered directly to the PCB cannot be removed without desoldering. Hotswap sockets provide flexibility for future switch changes.

### RJ45 Port - Interconnect

The RJ45 port connects the left and right halves of the keyboard together using a standard Ethernet cable.

**Required:** 2x RJ45 ports (1 per half)

#### RJ45 Port Installation

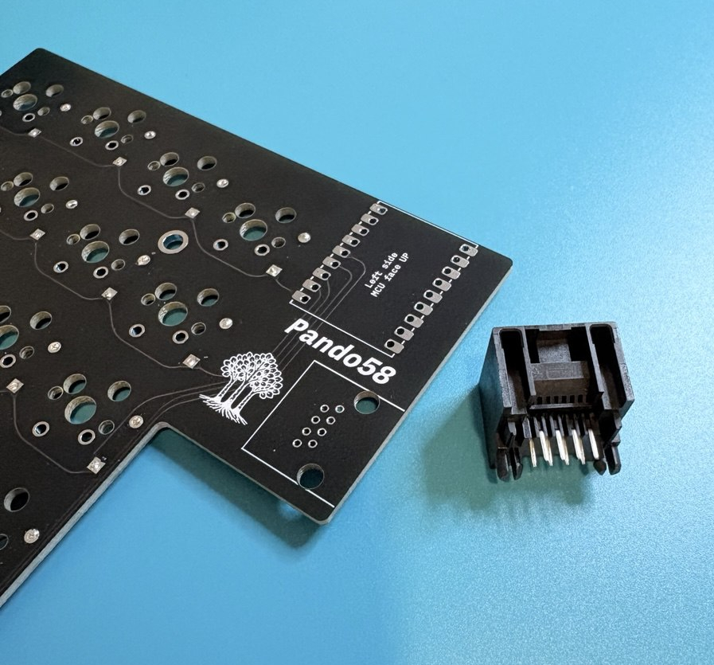
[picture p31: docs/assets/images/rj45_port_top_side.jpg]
RJ45 Port Top Side Installation


Install the RJ45 port on the **TOP side** of the PCB. Observe the footprint orientation silkscreen to ensure correct placement.

**Key points:**

- Molex RJ45 ports will snap in place on the two placeholder legs
- Clone ports may have smaller legs and won't snap in place - use tape to secure during soldering
- Ensure the port sits flush against the PCB

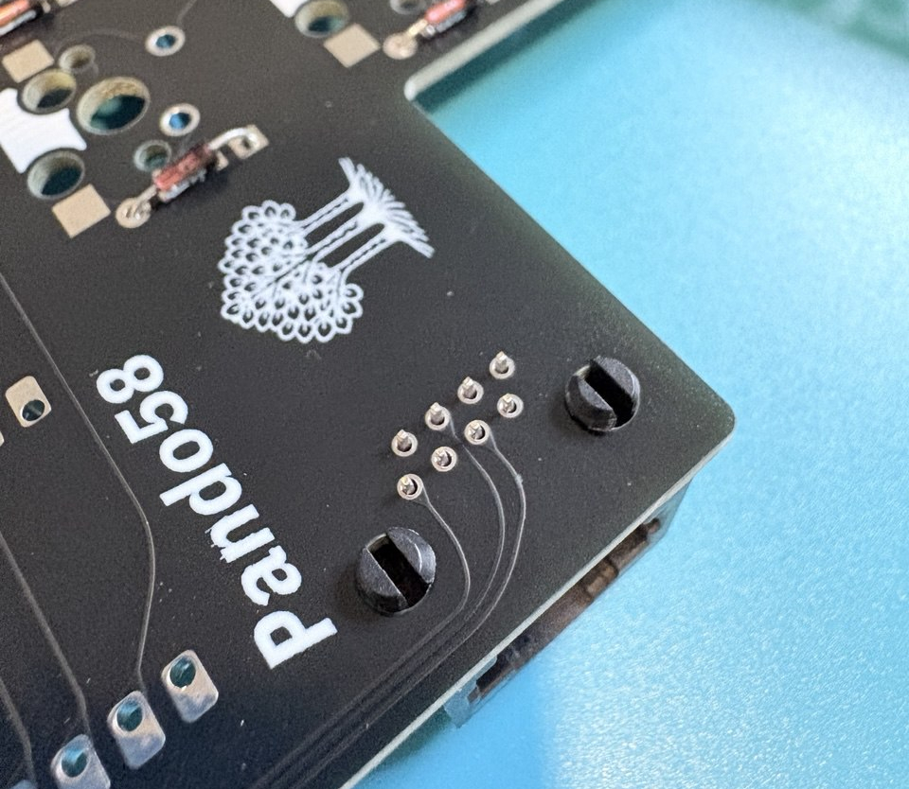
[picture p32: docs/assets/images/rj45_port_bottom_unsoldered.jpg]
RJ45 Port Bottom Side Unsoldered


The image above shows the back side with the RJ45 port in place but not yet soldered.

#### Soldering the RJ45 Port

Solder the RJ45 port from the **bottom side** of the PCB. Ensure all pins have good solder joints.

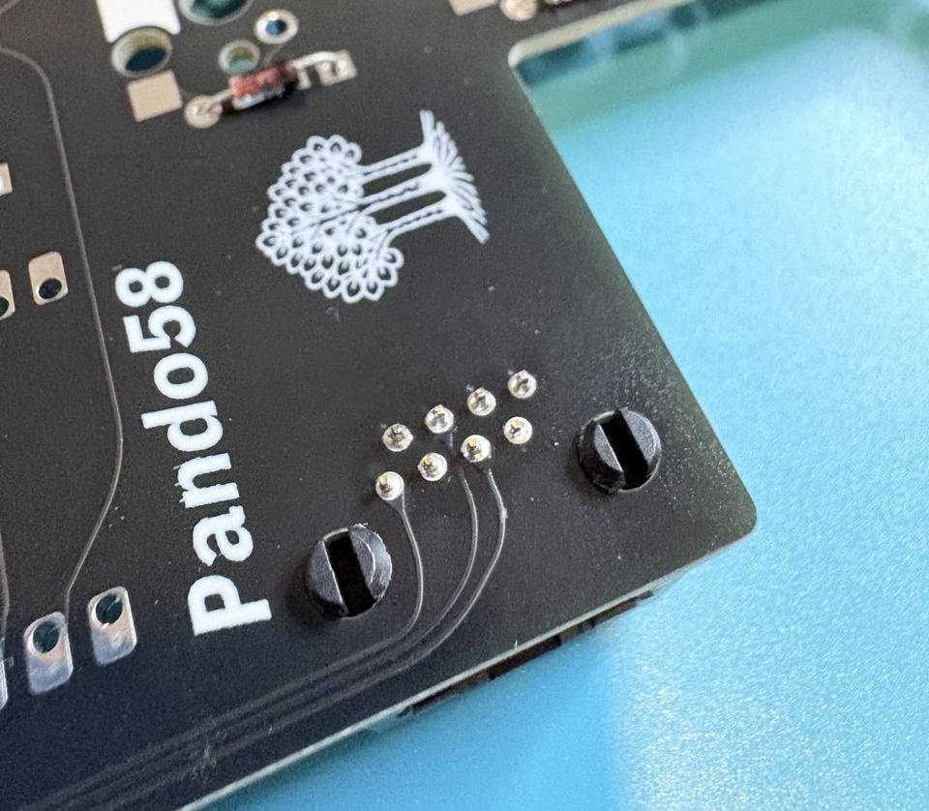
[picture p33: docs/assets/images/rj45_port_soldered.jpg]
RJ45 Port Soldered


The image above shows the completed soldering of the RJ45 port from the bottom side.

**Key points:**

- Heat each pad before applying solder
- Ensure all pins have solid solder joints
- Avoid bridging adjacent pins
- Don't overheat (plastic housing can be heat-sensitive)

#### Completed RJ45 Installation

**Verify before moving on:**

- RJ45 port is flush against the PCB
- All pins are soldered with good joints
- No solder bridges between pins
- Port orientation matches footprint silkscreen

### RP2040 Zero MCU

The RP2040 Zero microcontroller is the brain of the Pando58 keyboard. This guide covers installation using female header sockets (recommended) which allows the MCU to be removable. The same steps apply for direct soldering (alternative), where the male header pins are soldered directly to the PCB.

**Required:**

- 2x RP2040 Zero microcontrollers (1 per half)
- 4x 9-pin male header pins (2 rows per half)
- 4x 9-pin female header sockets (2 rows per half, optional but recommended for removable MCU)

#### Installation Methods

**Two options are available:**

1. **Using female header sockets (Recommended)** - Allows easy MCU removal if it needs replacement
2. **Direct soldering** - Male header pins soldered directly to PCB (permanent installation)

> **Warning:** Direct soldering makes MCU removal extremely difficult. Desoldering an MCU risks damaging both the MCU and the PCB.

#### Using Female Header Sockets (Recommended)

##### Preparing the Headers

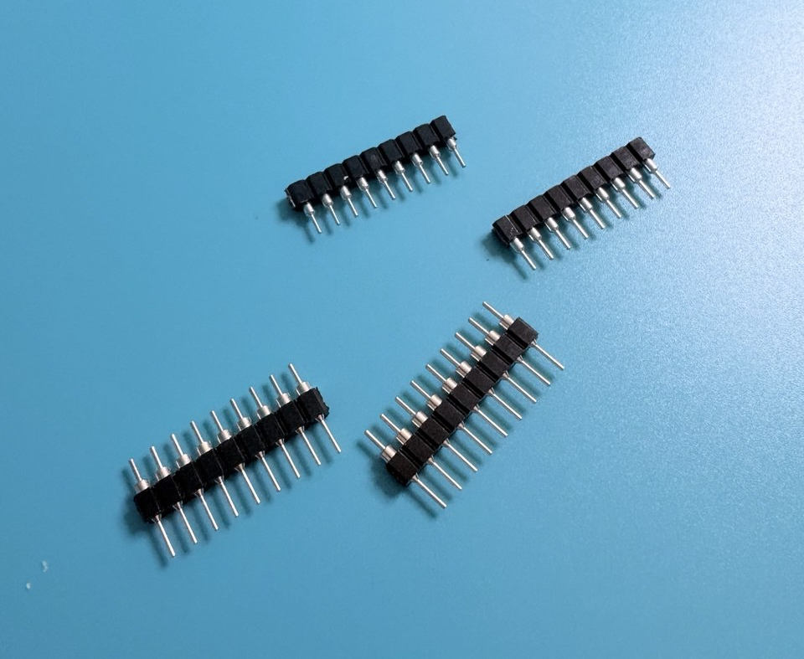
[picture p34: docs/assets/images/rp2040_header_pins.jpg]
RP2040 Header Pins


Pictured above are 2 rows of female header sockets (top) and 2 rows of male header pins.

The RP2040 Zero uses **SIP (Single In-line Package) headers** with 2.54mm spacing. These typically come in longer strips (e.g., 40 pins in a row). You'll need to snap off **9 pins per row, 2 rows** (18 pins total per MCU).

> **Note:** Pando58 PCB only uses the side pins of the RP2040 Zero (9+9 = 18 pins), not the bottom 5 pins. This saves on pin headers.

##### Installing Female Header Sockets to PCB

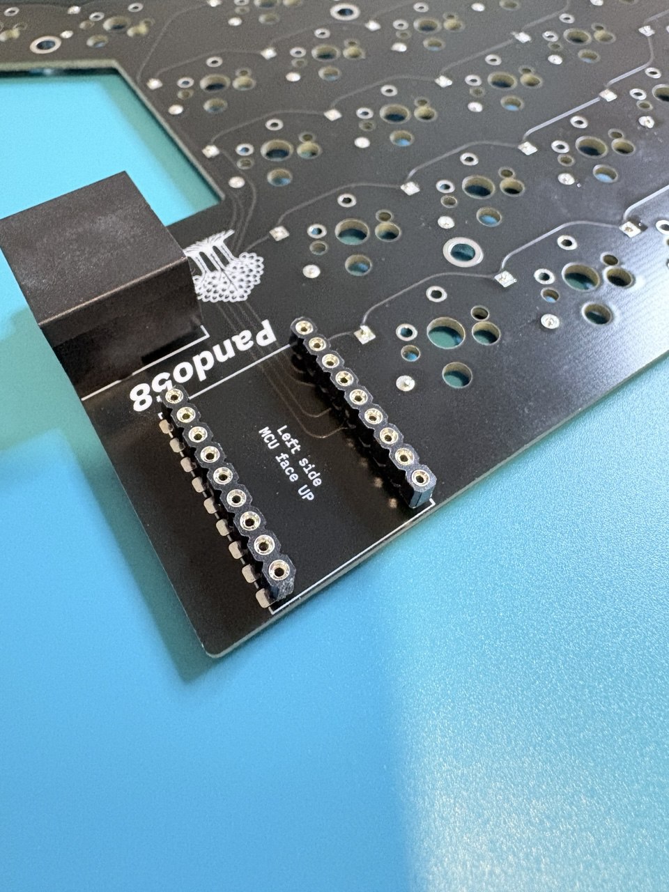
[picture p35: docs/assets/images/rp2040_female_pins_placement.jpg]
RP2040 Female Pins Placement


Insert the female header sockets into the **RP2040 Zero footprint** on the **TOP** of the PCB. The silkscreen text says "MCU face up".

**Key points:**

- Ensure sockets are inserted in the correct holes (2 rows of 9 pins)
- Sockets should be flush against the PCB
- Verify female header sockets are inserted on the top side of the PCB

##### Preparing for Soldering

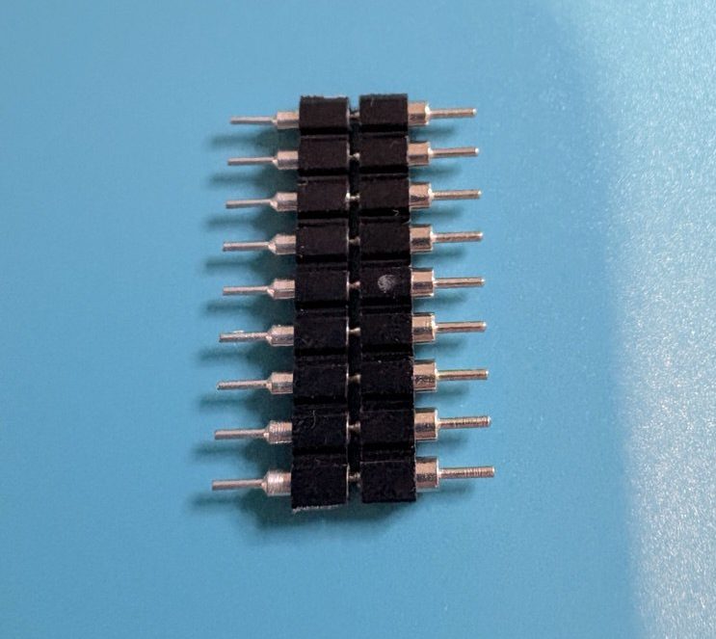
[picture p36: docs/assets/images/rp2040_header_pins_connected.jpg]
RP2040 Header Pins Connected


Pictured above are female header sockets connected to male header pins in the correct alignment.

Connect the male header pins onto the female header sockets on the PCB.

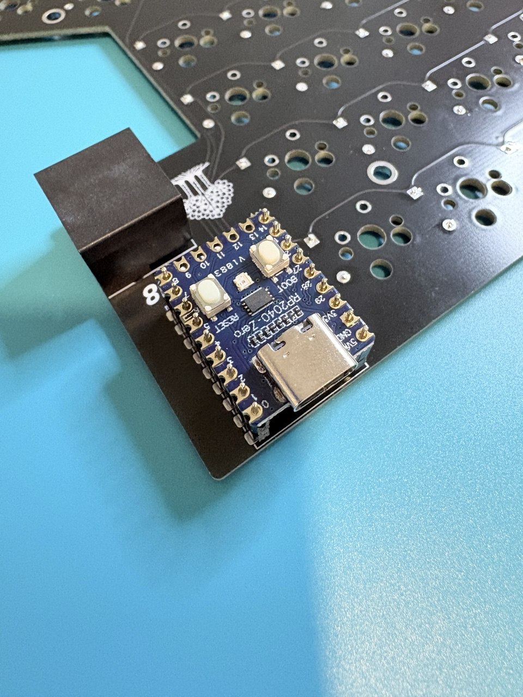
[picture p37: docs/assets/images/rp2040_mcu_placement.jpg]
RP2040 MCU Placement


Place the RP2040 Zero MCU onto the male header pins to verify fit before soldering. The MCU faces up with Boot and Reset buttons on top, and USB-C port facing outwards (away from the keyboard). All components should align properly.

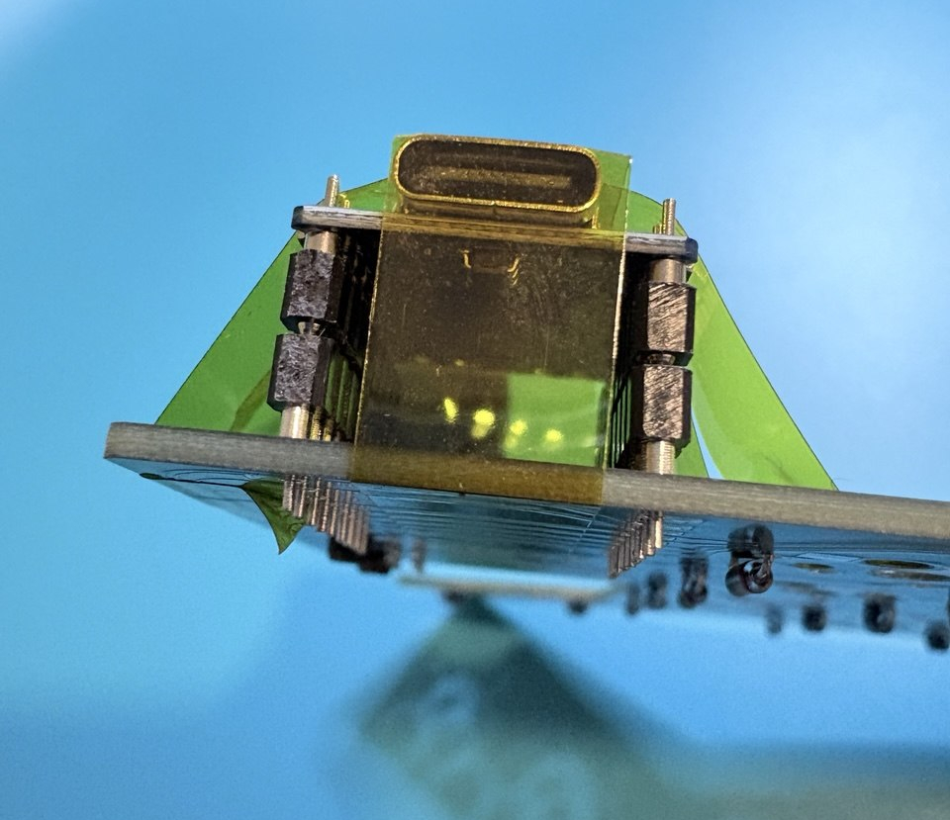
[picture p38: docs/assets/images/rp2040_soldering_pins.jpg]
RP2040 Header Pins Alignment


Use **Kapton tape** or other removable tape (like painter's tape) to secure the female header sockets to the PCB before soldering. Use any tape that doesn't permanently stick or damage the PCB. This prevents movement during soldering and ensures sockets stay flush.

The image above shows a top-side view with the 2 rows of female header sockets aligned vertically.

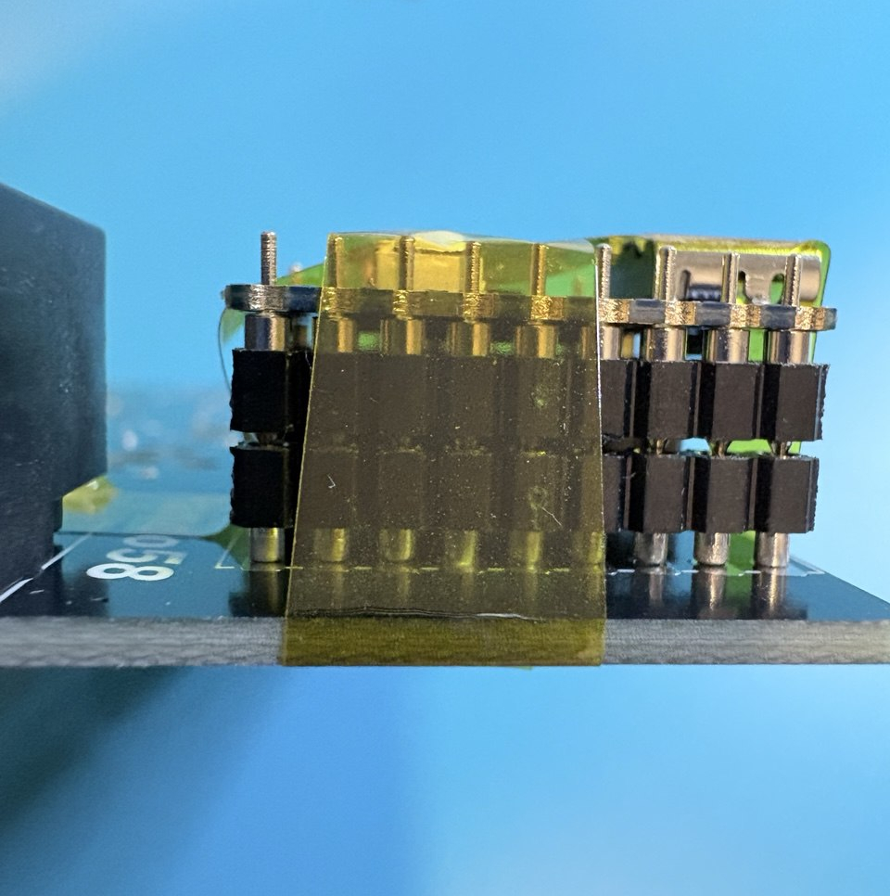
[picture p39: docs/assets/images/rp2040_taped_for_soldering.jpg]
RP2040 Taped for Soldering


The image above shows a side view with the female header sockets aligned vertically.

**Key points:**

- Female header sockets must be flush against the PCB
- MCU faces up with USB-C port facing outwards
- Female header sockets should be aligned vertically in 2 rows of 9 pins
- Tape prevents sockets from shifting during soldering
- Use removable tape that won't damage the PCB

##### Soldering the Female Header Sockets to PCB

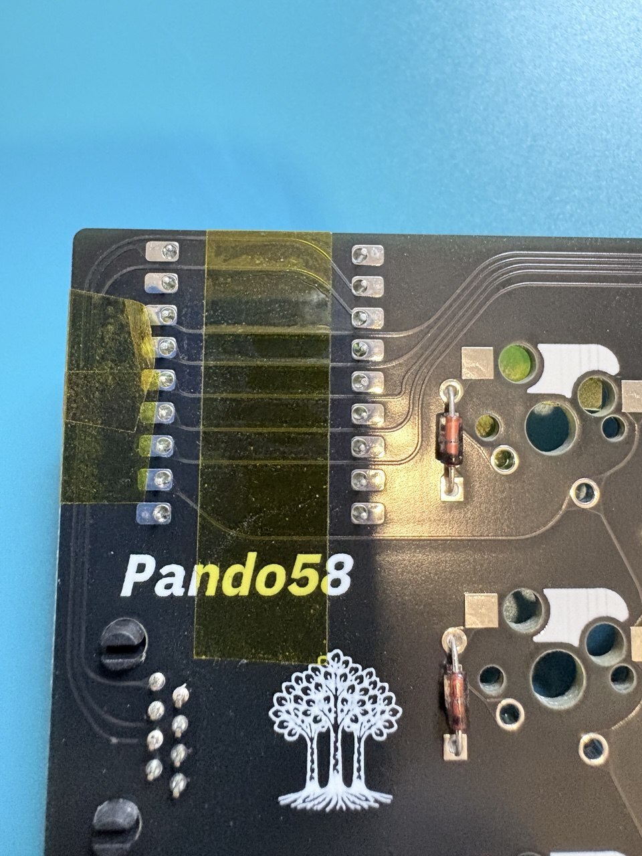
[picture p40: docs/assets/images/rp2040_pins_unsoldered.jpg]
RP2040 Pins Unsoldered


The image above shows the back of the PCB with the female header sockets in place but not yet soldered.

Solder the female header socket pins to the PCB from the **back** of the PCB. Start by soldering each **corner pin** to secure the sockets in place, then solder the rest of the pins.

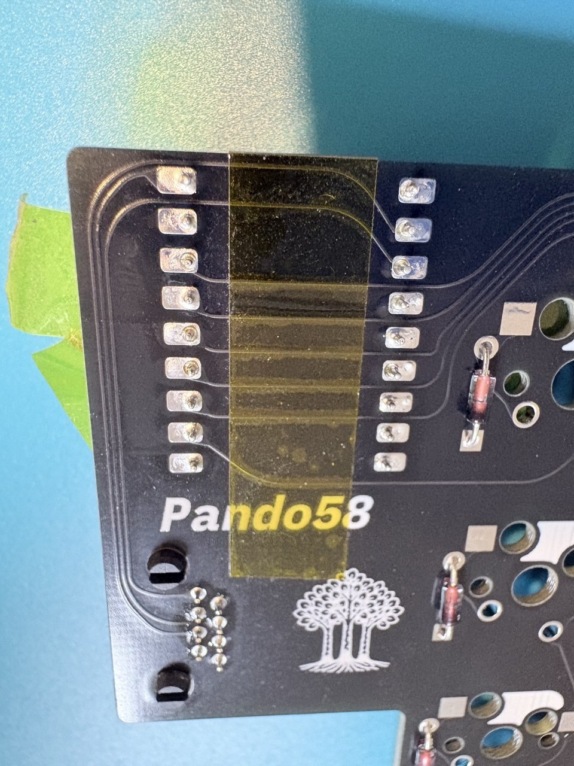
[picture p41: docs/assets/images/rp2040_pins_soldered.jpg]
RP2040 Pins Soldered


The image above shows the female header sockets fully soldered from the back of the PCB.

**Key points:**

- Solder from the back of the PCB
- Start with corner pins to secure the sockets in place
- Ensure all 18 pins have solid solder joints
- Avoid bridging adjacent pins
- Don't overheat (plastic housing can be heat-sensitive)

##### Soldering the MCU to the Male Header Pins

After soldering the female header sockets to the PCB, the male header pins are still connected to them with the RP2040 Zero MCU placed on top.

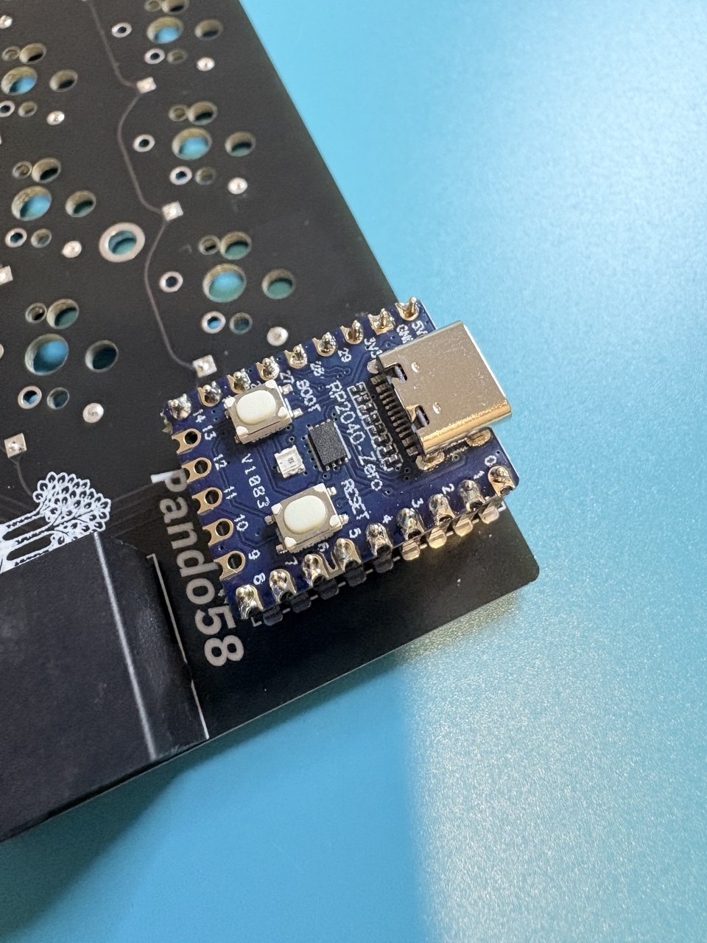
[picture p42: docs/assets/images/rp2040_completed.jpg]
RP2040 Zero Completed


The image above shows the completed RP2040 Zero installation.

**Steps:**

1. Ensure the MCU is properly seated on the male header pins
2. Optionally use Kapton tape to secure the MCU in place if it tends to move
3. Solder the male header pins to the MCU from the **top side**
4. Start with corner pins to secure the MCU, then solder the remaining pins
5. Remove tape if used

**Key points:**

- MCU faces up with USB-C port facing outwards
- Apply minimal heat to avoid damaging the MCU
- Solder all 18 pins (2 rows of 9 pins)
- Start with corner pins to secure alignment

**Verify before moving on:**

- All female header socket pins are soldered to PCB with good joints
- No solder bridges between pins
- All male header pins are soldered to MCU
- RP2040 Zero MCU is properly seated in the female header sockets
- MCU faces up with USB-C port facing outwards

#### Direct Soldering (Alternative)

The RP2040 Zero typically comes with corresponding male header pins. Solder these male pins directly to the PCB.

**Step 1: Preparing the Headers**

Snap 4x 9-pin male header pins (2 rows per MCU) if needed. These typically come in longer strips (e.g., 40 pins in a row).

**Step 2: Installing Male Header Pins to PCB**

1. Insert the male header pins into the RP2040 Zero footprint on the **TOP** of the PCB
2. Use Kapton tape or removable tape to secure the pins in place
3. Solder all 18 pins to the PCB from the **back**, starting with corner pins
4. Remove tape after soldering is complete

**Step 3: Soldering MCU to Header Pins**

1. Place the RP2040 Zero MCU onto the male header pins
2. Ensure MCU faces up with USB-C port facing outwards
3. Solder the 18 pins on the MCU side, starting with the corner pins
4. Apply minimal heat to avoid damaging the MCU

> **Warning:** This method makes MCU removal extremely difficult. Desoldering an MCU risks damaging both the MCU and the PCB.

**Verify before moving on:**

- All male header pins are soldered to PCB with good joints
- No solder bridges between pins
- All male header pins are soldered to MCU
- MCU faces up with USB-C port facing outwards

### Switches

The switches are installed between the switch plate and the PCB. This section covers switch installation and final assembly.

#### Hardware

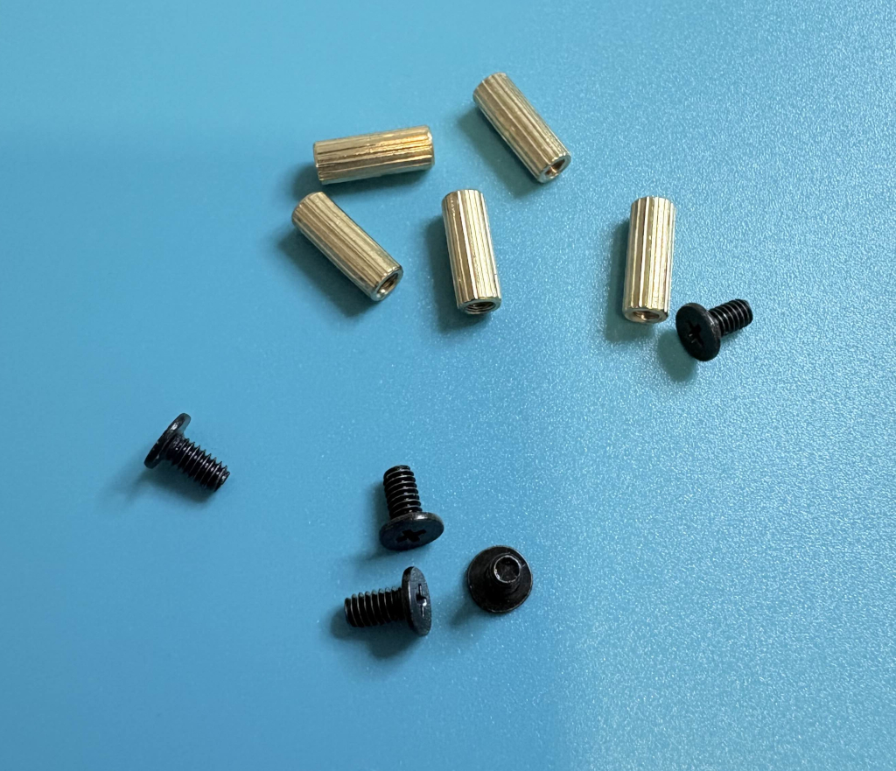
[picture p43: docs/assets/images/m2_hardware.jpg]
M2 Hardware


The above image shows 5x M2 8mm brass standoffs and 10x M2 4mm screws, which is the correct quantity for one half of the keyboard.

**Required:**

- 10x M2 8mm brass standoffs (5 per half)
- 20x M2 4mm screws (10 per half)
- 58x switches (29 per half)
- 2x Switch plates
- 2x Bottom plates

#### Preparing the Switch Plate

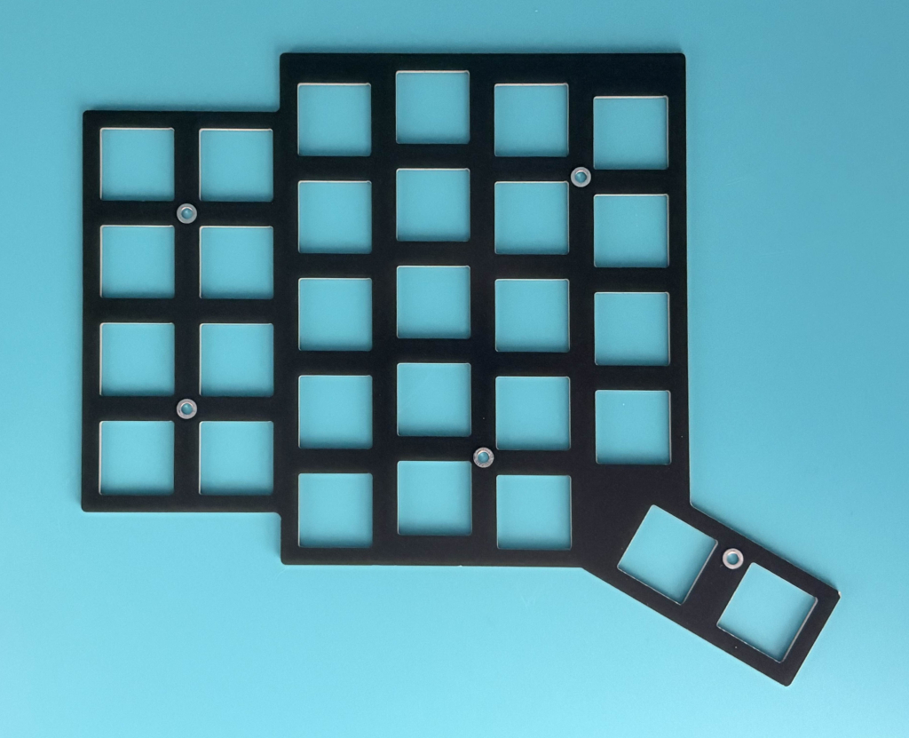
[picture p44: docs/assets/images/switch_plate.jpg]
Switch Plate


The switch plate is reversible and works for both left and right halves.

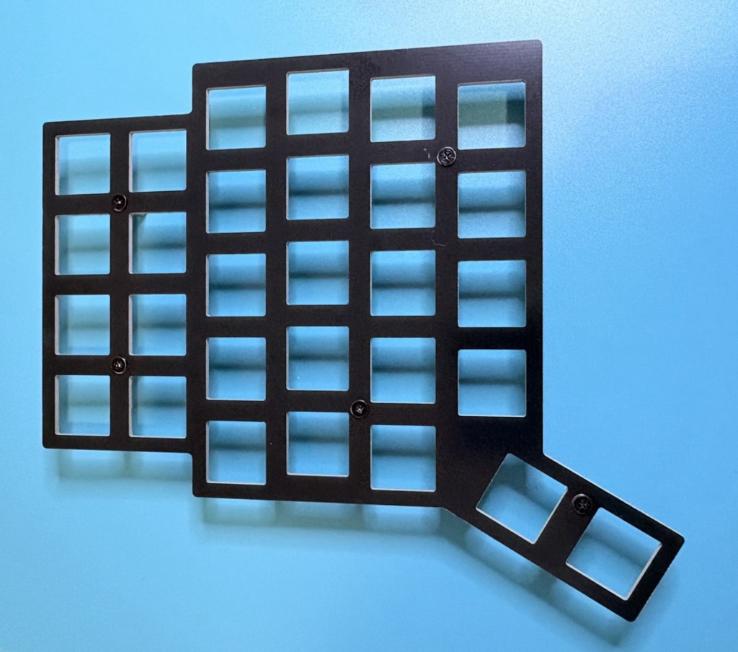
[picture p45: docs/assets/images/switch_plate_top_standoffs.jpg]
Switch Plate Top with Standoffs


Screw the standoffs from the top side of the plate.

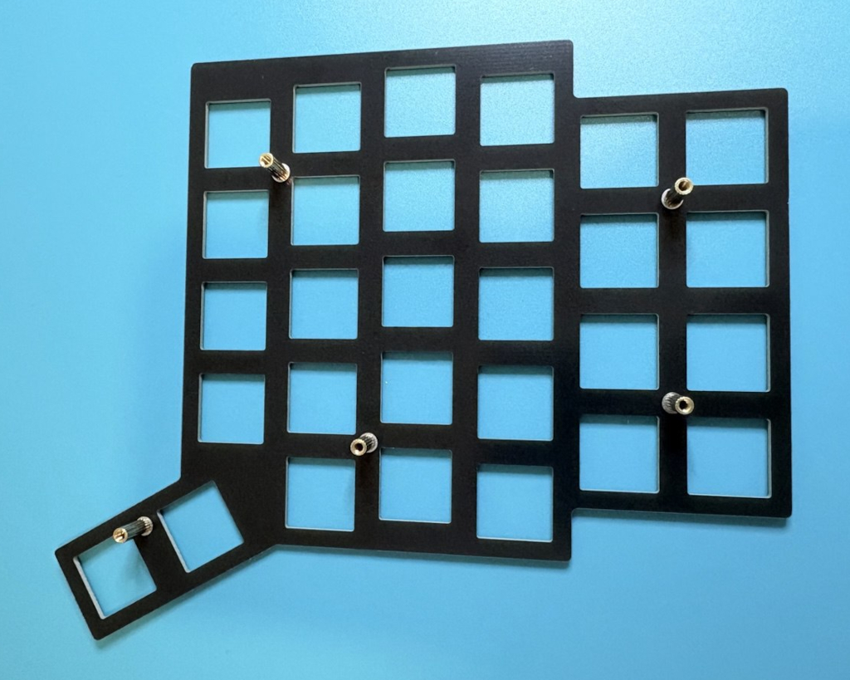
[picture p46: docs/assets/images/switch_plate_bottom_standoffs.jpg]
Switch Plate Bottom with Standoffs


#### Installing Switches on the Plate

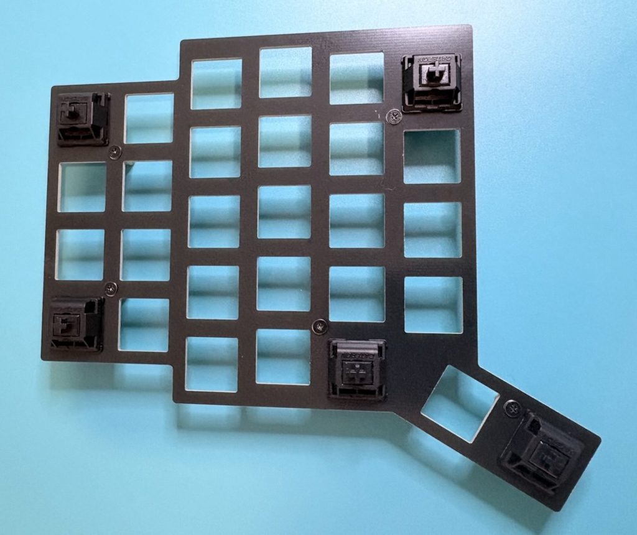
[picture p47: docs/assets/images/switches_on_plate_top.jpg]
Switches on Plate - Top


Insert switches into the plate. Place switches on the edges and near the standoffs for structural support. The switch pins must face **up** (towards the top of the plate) to align with the hotswap sockets.

**Key points:**

- Switch pins face up to align with hotswap sockets
- Place switches near edges and standoffs for structural support

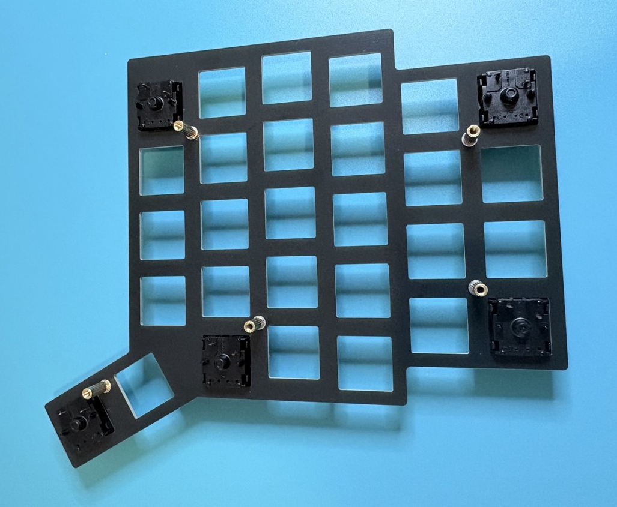
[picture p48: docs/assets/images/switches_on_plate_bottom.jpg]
Switches on Plate - Bottom


#### Attaching Switches to PCB

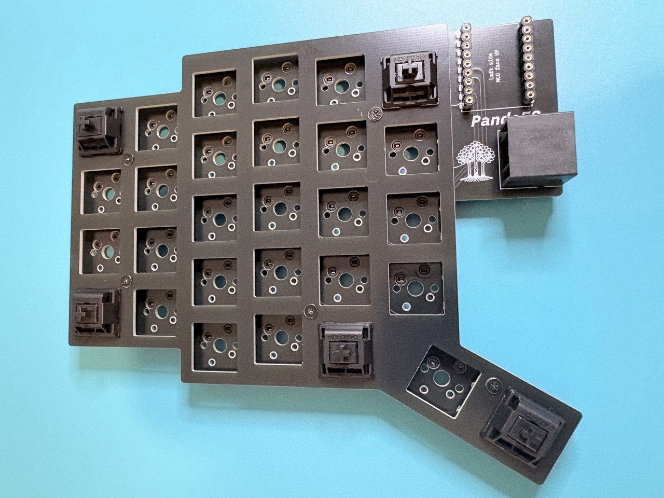
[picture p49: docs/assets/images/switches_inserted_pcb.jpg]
Switches Inserted into PCB


Place the switch plate onto the PCB. Fully press the switches into the hotswap sockets.

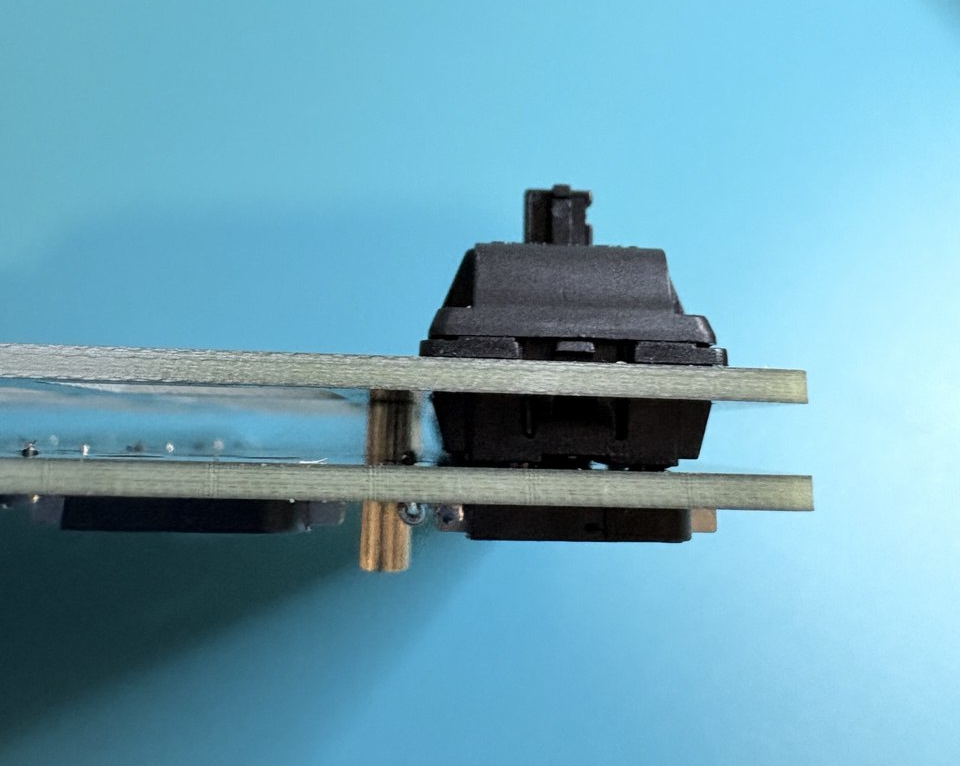
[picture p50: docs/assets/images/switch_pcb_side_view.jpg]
Switch PCB Side View


The image above shows a switch sitting flush against the PCB.

**Key points:**

- Fully press switches into hotswap sockets
- Ensure switches sit flush against PCB

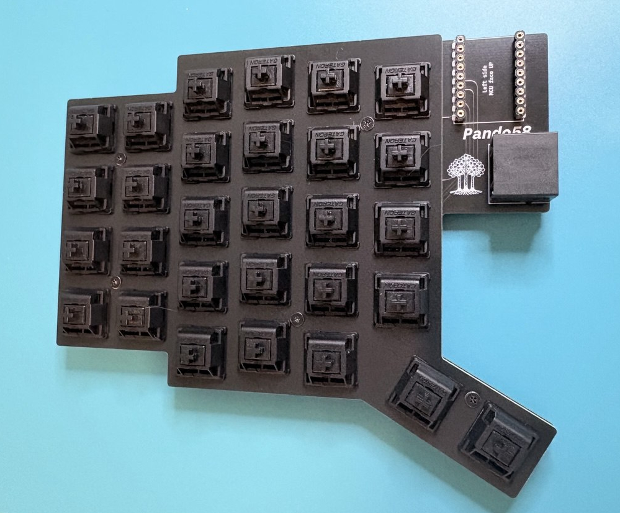
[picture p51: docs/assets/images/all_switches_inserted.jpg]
All Switches Inserted


The above image shows all 29 switches inserted into the plate for one half of the keyboard.

#### Attaching the Bottom Plate

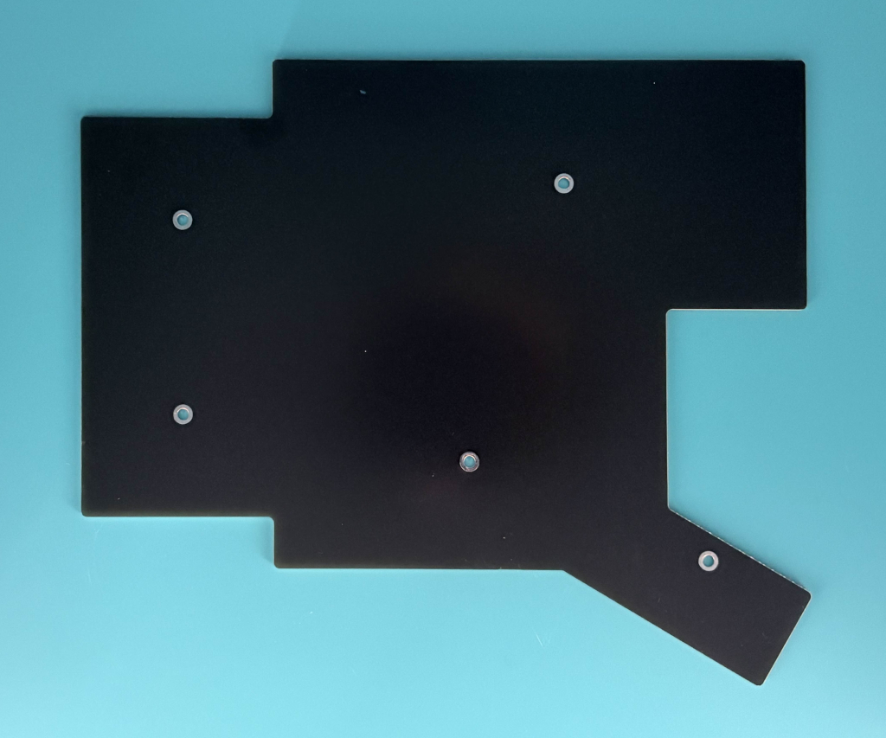
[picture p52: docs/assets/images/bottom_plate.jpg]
Bottom Plate


The bottom plate provides structural support and protection.

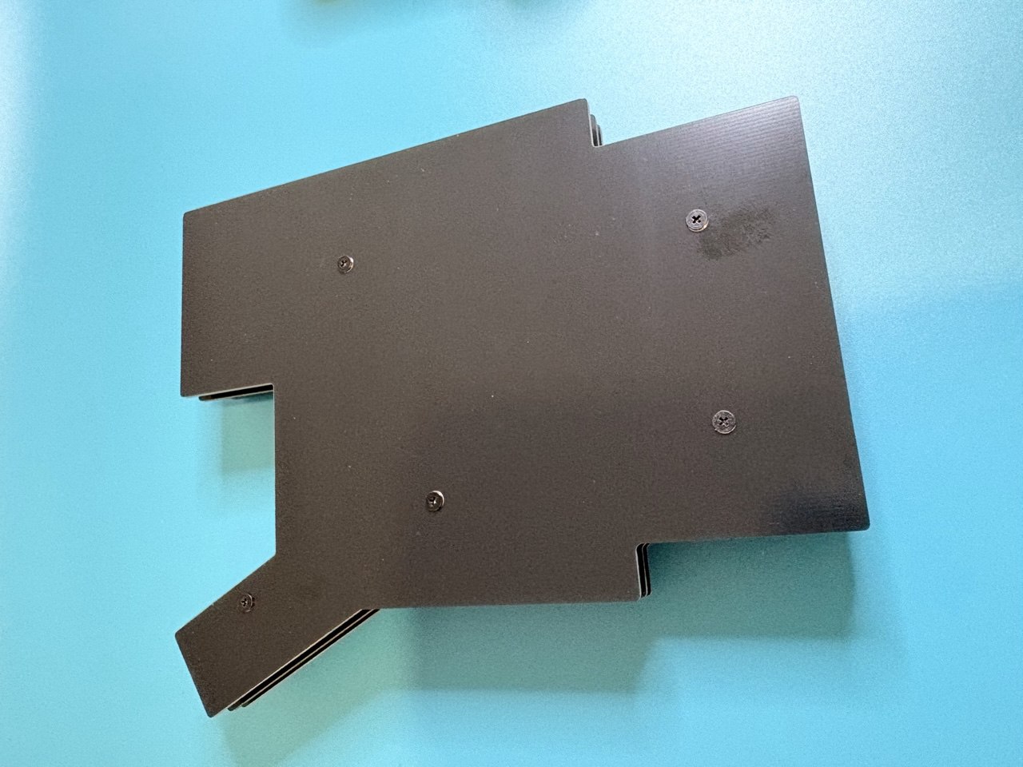
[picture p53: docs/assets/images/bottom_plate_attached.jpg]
Bottom Plate Attached


Screw the bottom plate to the standoffs.

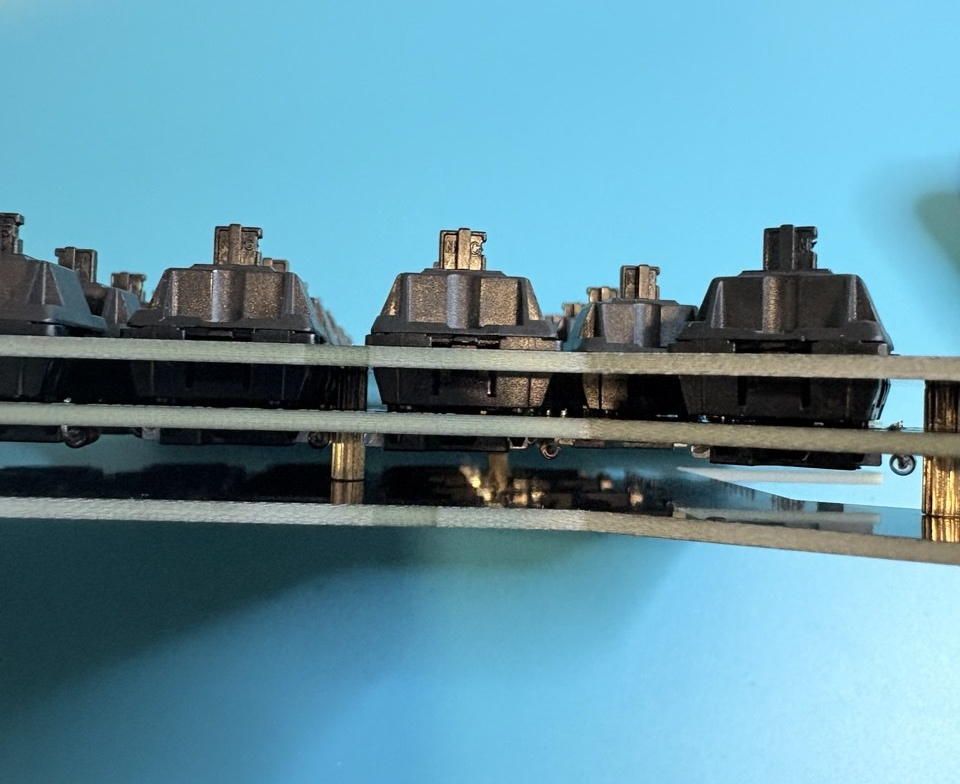
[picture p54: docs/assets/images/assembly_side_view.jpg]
Assembly Side View


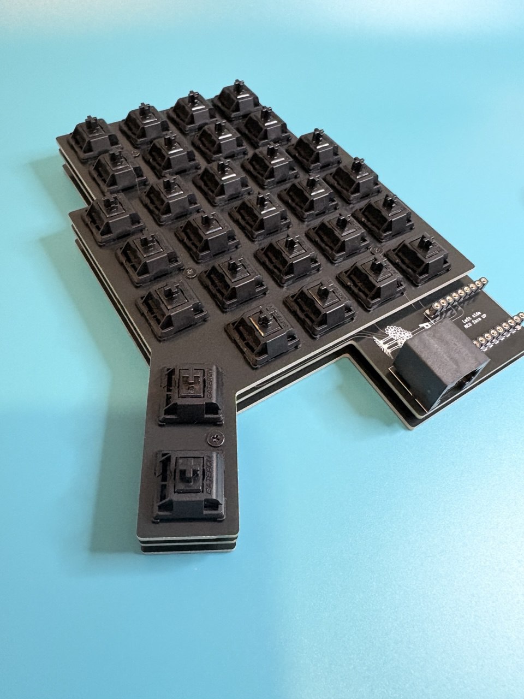
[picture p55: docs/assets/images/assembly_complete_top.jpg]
Assembly Complete


The image above shows the fully assembled keyboard with switches and bottom plate attached.

### Keycaps and Optional Bumpons

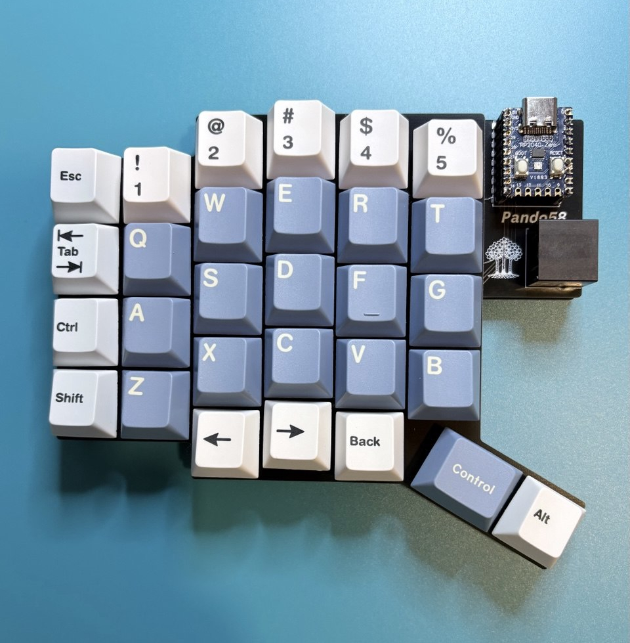
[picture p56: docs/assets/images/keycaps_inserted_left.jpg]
Keycaps Inserted Left


Insert the keycaps onto the switches. The above image shows the top view with keycaps inserted for the left hand side of the keyboard - this is the final step of assembly.

> **Optional:** You can also place 3M SJ5302 bumpons to the bottom side of the keyboard (4 on each side, 8 total).

This completes the build! Next, you'll need to install firmware onto the MCU. See the [Firmware](firmware.md) page for instructions.

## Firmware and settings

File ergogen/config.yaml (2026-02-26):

meta:
  engine: 4.1.0
  name: Pando58
  author: Julian Yap
  github: jyap808
  version: v1.2.0
  footer_text: &footer_text "Designed in Washington, USA - by jyap - v1.2"

units:
  # Proxy Spacing Variables
  kx: U
  ky: U
  # Padding Variables
  px: kx + 2
  py: ky + 2
  # Defaults to M2 Screws
  screwSize: 1.1
  # M2 spacer size
  spacerSize: 1.6
  # Tooling size
  toolingSize: 1.6
  standoffHeight: 10
  standoffCoverHeight: 25
  baseFillet: 1.2
  switchFillet: 0.5

  csWall: 3.6              # Wall thickness
  csMargin: 0.5            # PCB clearance
  csLip: 3                 # Lip height above plate (7-8mm full coverage, 2-3mm floating)
  csBottomZ: 2.5           # Bottom plate thickness
  csWallZ: csLip + standoffHeight + csBottomZ      # Total wall height

  csScrewSize: 1.6         # M3 screws
  csSOSize: 2.7            # M3 round stand offs. 5mm OD
  # Sandwich
  csWallSW: 7              # Wall thickness
  csFilletSW: 3            # Fillet

points:
  zones:
    matrix:
      key:
        tags: ['key']
      # Fix placement on KiCAD sheet.
      anchor:
        shift: [70, -200]
      columns:
        # Sofle v2/RGBv3 aggressive pinky stagger based
        outer:
          rows.mod.skip: true
          key.column_net: col0
        pinky:
          rows.mod.skip: true
          key.column_net: col1
        ring:
          key:
            stagger: 9
            column_net: col2
          rows.mod.column_net: col1
        middle:
          key:
            stagger: 2.5
            column_net: col3
          rows.mod.column_net: col2
        index:
          rows.mod.skip: true
          key:
            stagger: -2.5
            column_net: col4
          rows.mod.column_net: col3
        inner:
          rows.mod.skip: true
          key:
            stagger: -2.5
            column_net: col5
      rows:
        # Four main rows, one partial row.
        # Ergogen uses Cartesian Coordinates as opposed to a keyboard matrix
        mod:
          row_net: row4
        bottom:
          row_net: row3
        home:
          row_net: row2
        top:
          row_net: row1
        num:
          row_net: row0
    thumbs:
      key:
        tags: ['key']
      anchor:
        ref: matrix_index_bottom
        shift: [0, -1U]
      columns:
        top:
          key:
            column_net: col3
        middle:
          key:
            width: 1.25U
            origin: [-0.6U, -0.8U]
            splay: -30
            column_net: col4
        bottom:
          key:
            # (1.25+1)/2 - 1 = 0.125
            shift: [0.125U, 0]
            column_net: col5
      rows:
        cluster:
          row_net: row4
    # Mounts - Inner
    mount_inner_top_left:
      anchor:
        ref: matrix_outer_top
        shift: [0.5kx, 0.5ky]
    mount_inner_bottom_left:
      anchor:
        ref: matrix_outer_bottom
        shift: [0.5kx, 0.5ky]
    mount_inner_top_right:
      anchor:
        ref: matrix_inner_top
        shift: [-0.5kx, 0.55ky]
    mount_inner_bottom_middle:
      anchor:
        ref: thumbs_top_cluster
        shift: [-0.5kx, 0.55ky]
    mount_inner_bottom_right:
      anchor:
        ref: thumbs_bottom_cluster
        shift: [-0.55kx, 0.3ky]
    # Mounts - Sandwich Outer
    mount_sw_outer_top_left:
      anchor:
        ref: matrix_outer_num
        shift: [-0.5kx-csWallSW/2-csMargin, 0.5ky+csWallSW/2+csMargin]
    mount_sw_outer_top_middle:
      anchor:
        ref: matrix_middle_num
        shift: [0.5kx, 0.5ky+csMargin+csWallSW/2+1]
    mount_sw_outer_bottom_left:
      anchor:
        ref: matrix_outer_bottom
        shift: [-0.5kx-csWallSW/2-csMargin, -0.5ky-csWallSW/2-csMargin]
    mount_sw_outer_bottom_middle:
      anchor:
        ref: thumbs_top_cluster
        shift: [-0.5kx, -0.5ky-csMargin-csWallSW/2-1]
    mount_sw_outer_bottom_right:
      anchor:
        ref: thumbs_bottom_cluster
        shift: [-0.55kx, 0.5ky+csMargin+csWallSW/2+1]
    # Mounts - Sandwich Cover
    mount_sw_cover_top_right:
      anchor:
        ref: matrix_middle_num
        shift: [4U+csWallSW/2-csMargin, 0.5ky+csWallSW/2+csMargin]
    mount_sw_cover_middle_right:
      anchor:
        ref: matrix_middle_num
        shift: [4U+csWallSW/2-csMargin, -2U-3]
  mirror: &mirror
    ref: matrix_inner_num
    distance: 5kx
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

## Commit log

2026-02-26 Add key tags to actual keys. Preparation for mount point refactor.
2026-02-26 Refactor Mount Inner points
2026-02-26 Refactor Mount Sandwich points
2026-03-20 Add ceoloide footprints submodule
2026-03-20 Add custom Ergogen footprints for Pando58 keyboard
    - rp2040zero: RP2040 Zero MCU with centered body origin and optional button cutout/bottom pins
    - pando58_logo: Custom logo silk/fab graphic
    - rj45_molex_43860_3wire: Molex 43860 RJ45 footprint for 3-wire split keyboard interconnect (GND, DATA, VCC)
2026-03-22 Add 3D-printable case
    [Pando58Case.FCStd]
2026-03-23 Add 3D printed case gallery images and cross-references
2026-03-31 Update assembly detail images
2026-04-25 Clarify switch plate must be attached before soldering switches to PCB
2026-05-29 keyboards/jyap808/pando58: sync with upstream QMK merge
    - Configs migrated from `config.h` to `keyboard.json` (watchdog transport)
    - Device version bumped to 1.2.0
    - Default keymap formatting cleanup
    - Added README
2026-10-14 Relicense hardware under CERN-OHL-S v2
    Replace CC BY-SA 4.0 with CERN-OHL-S v2 for the hardware sources
    (PCB/ergogen, case, docs). Firmware in keyboards/ stays
    GPL-2.0-or-later.
